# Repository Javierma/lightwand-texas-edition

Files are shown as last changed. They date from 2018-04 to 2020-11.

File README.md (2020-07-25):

# Lightwand Texas Edition v 2.0

Copyright (C) May 2018, Javier Martínez Arrieta

The LightWand Texas Edition controller is released under an Attributtion-ShareAlike 4.0 International (CC BY-SA 4.0). Therefore, anyone is free to:

-Share - copy and redistribute the material in any medium or format

-Adapt - remix, transform, and build upon the material for any purpose, even commercially.

This is the Lightwand Texas Edition project, a light painting project that makes use of a TM4C123 (TIVA) board as a controller in order to read the image information and transmit it to the LED strip according to the settings.

The following folders contain all the necessary things:
	
-CCS project: Contains the software code to be uploaded to the board

-Eagle project: Contains the hardware design

-FreeCAD design: Contains the 3D design of the box to cover the hardware

-Sketchup design: Contains the 3D design of the hardware

-Lightwand Texas Edition English Guide: The manual to be used to know about the different HW parts, soldering steps, creating PNM images and how to navigate through the different menus 

In order to know how to import the project in Code Composer Studio, configure the project settings and configure interrupts, go to the [wiki page](https://github.com/Javierma/lightwand-texas-edition/wiki)

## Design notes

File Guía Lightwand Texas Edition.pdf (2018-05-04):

# Lightwand Texas Edition

V 1.0

## Desarrollado por Javier Martínez Arrieta

## (martinezarrietajavier@gmail.com)

## Disponible en

## https://github.com/JavierMA/lightwand-

## texas-edition (https://github.com/JavierMA/lightwand-texas-edition)

### Índice

5.5. Suelde la tira de pines hembra (8 pines) para conectar el acelerómetro ADXL345
5.10. Desuelde los cables de la tira de LEDs, que podrá reutilizar para crear un cable más
5.11. Conecte el extremo libre del los cables con un conector molex hembra para conseguir
5.13. Finalmente, conecte el conector molex hembra con el macho ya soldado en la placa: 12
7.5. Paso 5: Rote la imagen 180º (únicamente si el movimiento del Lightwand lo hace de

### Tabla de figuras

### 1. Acerca del autor

Este Proyecto ha sido desarrollado por Javier Martínez Arrieta, ingeniero telemático (telecomunicaciones) aficionado a la electrónica. En caso de querer resolver una duda, saber más o incluso un posible curso puede escribir a martinezarrietajavier@gmail.com

Este y otros proyectos pueden encontrarse en https://www.github.com/JavierMA

### 2. Agradecimientos

Este proyecto está basado en el Proyecto Lightwand kosmonaut, desarrollado por Pablo de Miguel Morales (https://github.com/pablodmm), quien me ayudó en la realización de este Proyecto, por lo que me gustaría agradecerle a él y otras personas de AETEL que también me ayudaron. Adicionalmente, LightWand Kosmonaut se basa en el Proyecto de light painting desarrollado por Michael Ross. (http://mrossphoto.com/wordpress32/)

Por otra parte, algunas de las funciones que pueden verse en el software están basados o directamente recogidos de de ejemplos del curso de EdX ‘Embedded systems: shape the world’ o de Jonathan Valvano http://users.ece.utexas.edu/~valvano/arm/.

Para finalizar los agradecimientos y menciones, quisiera agradecer a Paul Stoffregen su tutorial (https://www.pjrc.com/tech/8051/ide/fat32.html) acerca de cómo entender el sistema de ficheros FAT 32 y su funcionamiento.

### 3. Licencia

El controlador LightWand Texas Edition se encuentra bajo la licencia Creative Commons, Attributtion-ShareAlike 4.0 International (CC BY-SA 4.0). Por ello, cualquiera es libre de:

- Compartir — Copiar y redistribuir el material en cualquier medio o formato
- Adaptar — Mezclar, transformar y crear a partir de este material, incluso con fines comerciales.

### 4. Imágenes compatibles

Las imágenes compatibles con el Lightwand Texas Edition son las imágenes de extensión PNM, que pueden crearse o convertirse mediante programas como GIMP, del cual dispone de un tutorial más adelante en esta guía.

### 5. Proceso de soldadura

Los siguientes pasos muestran el que se considera es el mejor procedimiento para la soldadura de todos los componentes en la placa. Como regla general, se recomienda soldar en primer lugar los componentes de menor altura (en este caso, los componentes SMD), y por último los de mayor altura, que en este caso son las tiras de pines macho que conectan la TIVA con la placa que contiene todos los componentes.

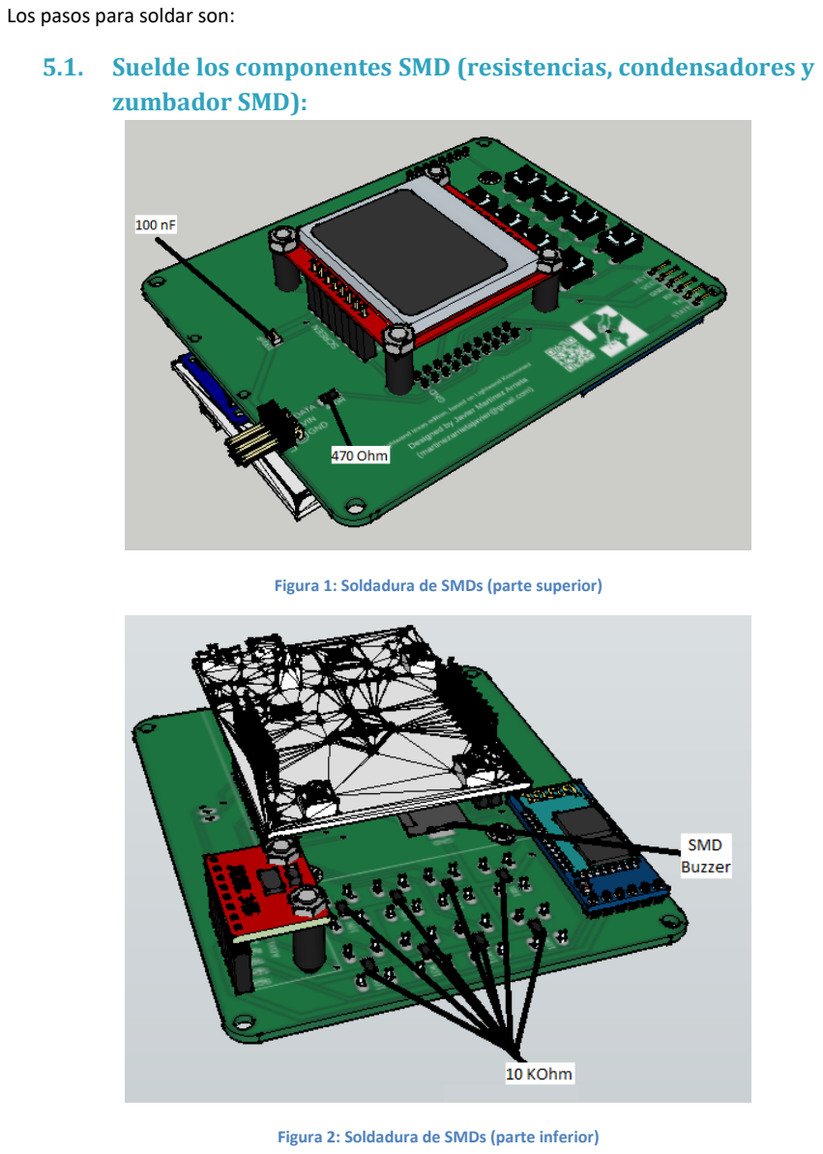
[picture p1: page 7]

Los pasos para soldar son:

### 5.1. Suelde los componentes SMD (resistencias, condensadores y zumbador SMD):

Figura 1: Soldadura de SMDs (parte superior)

Figura 2: Soldadura de SMDs (parte inferior)

### 5.2. Suelde los pulsadores:

Figura 3: Soldadura de pulsadores

### 5.3. Suelde el conector a la tira de LEDs:

Figura 4: Conector de la tira LED

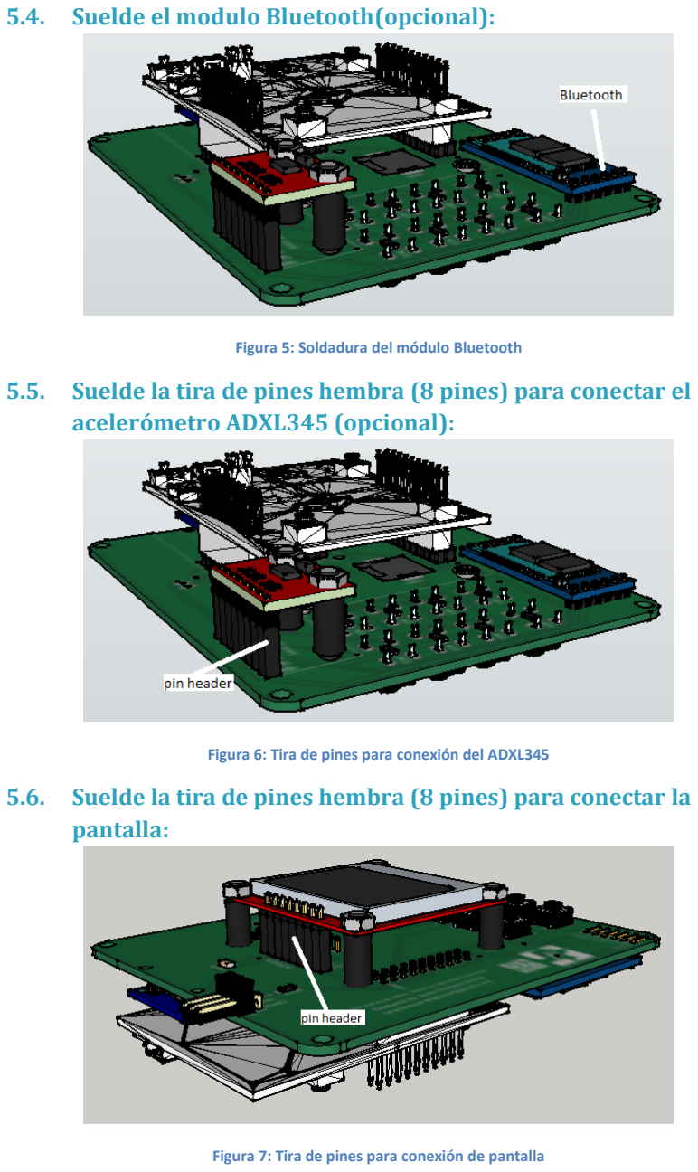
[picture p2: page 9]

### 5.4. Suelde el modulo Bluetooth(opcional):

Figura 5: Soldadura del módulo Bluetooth

### 5.5. Suelde la tira de pines hembra (8 pines) para conectar el acelerómetro ADXL345 (opcional):

Figura 6: Tira de pines para conexión del ADXL345

### 5.6. Suelde la tira de pines hembra (8 pines) para conectar la pantalla:

Figura 7: Tira de pines para conexión de pantalla

### 5.7. Suelde el adaptador de tarjetas microSD:

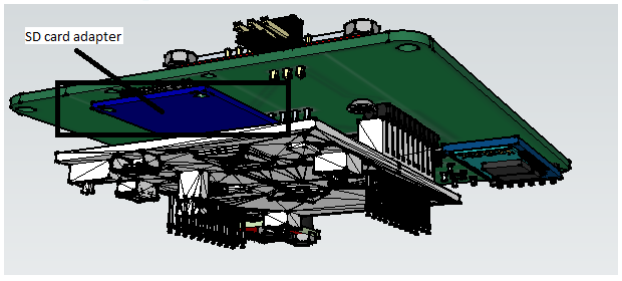
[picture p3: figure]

Figura 8: Soldadura del adaptador de microSD

### 5.8. A continuación, suelde las tiras de pines macho (2x10):

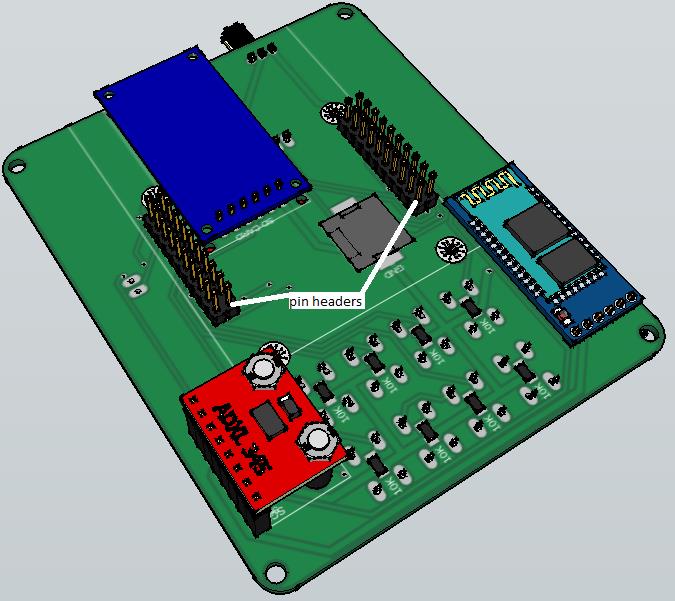
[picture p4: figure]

Figura 9: Soldadura de las tiras de pines macho

### 5.10. Desuelde los cables de la tira de LEDs, que podrá reutilizar para crear un cable más largo que unirá la tira con la placa:

Figura 10: Retirada de cable del final de la tira de LEDs

### 5.11. Conecte el extremo libre de los cables con un conector molex hembra para conseguir un resultado como el siguiente:

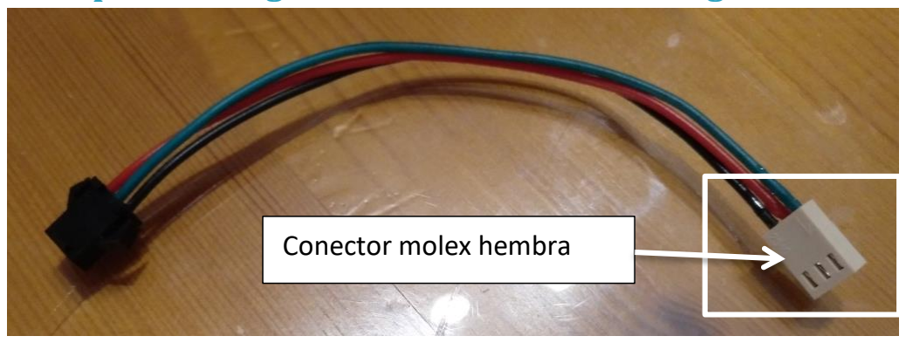
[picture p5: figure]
Conector molex hembra

Figura 11: Soldadura con el conector molex hembra

### 5.12. Conecte el conector negro del cable con el del cable unido a la tira de LEDs:

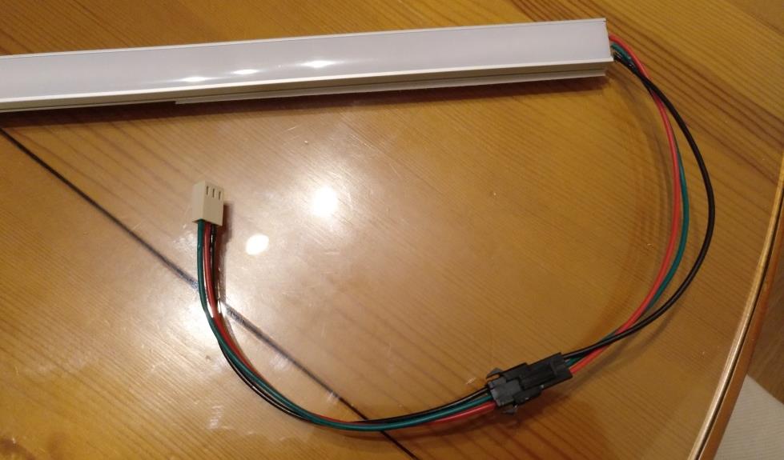
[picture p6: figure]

Figura 12: Conexión entre conectores negros

### 5.13. Finalmente, conecte el conector molex hembra con el macho ya soldado en la placa:

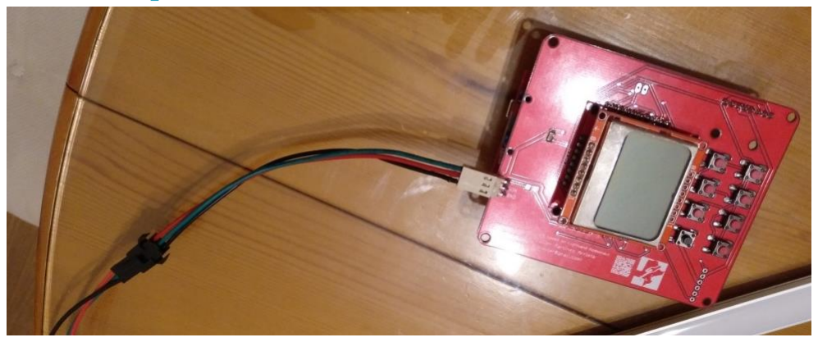
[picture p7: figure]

Figura 13: Conexión entre la tira de LEDs y la placa

### 6. Menús

Una vez que la placa recibe alimentación, en primer lugar se verificará que la tarjeta microSD conectada está formateada como FAT32.

Figura 14: Verificación del Sistema de ficheros

Tras la verificación, comienza la inicialización y se mostrará el menú principal:

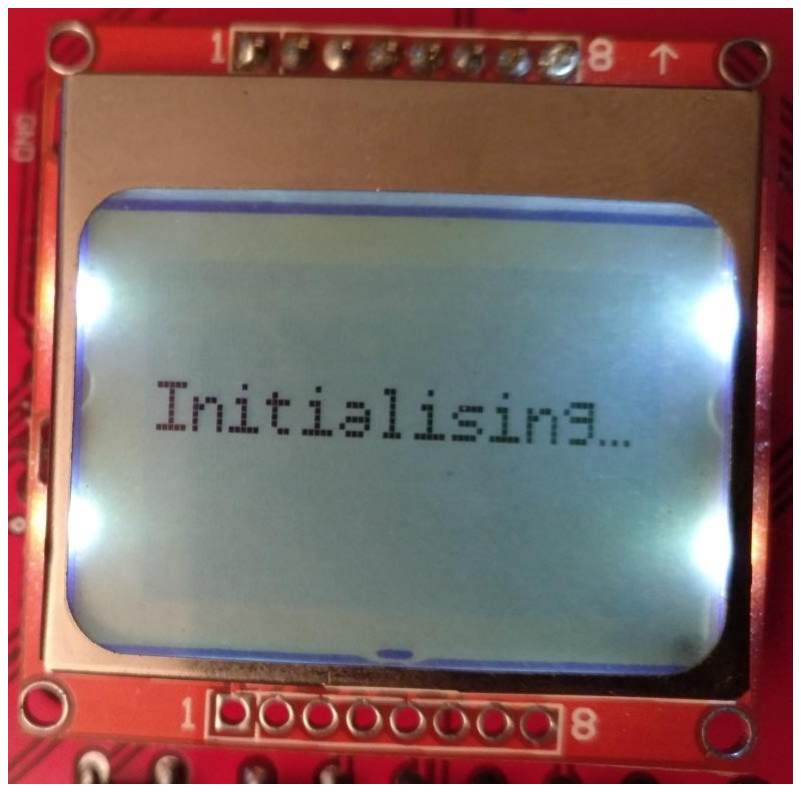
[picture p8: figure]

Figura 15: Inicialización

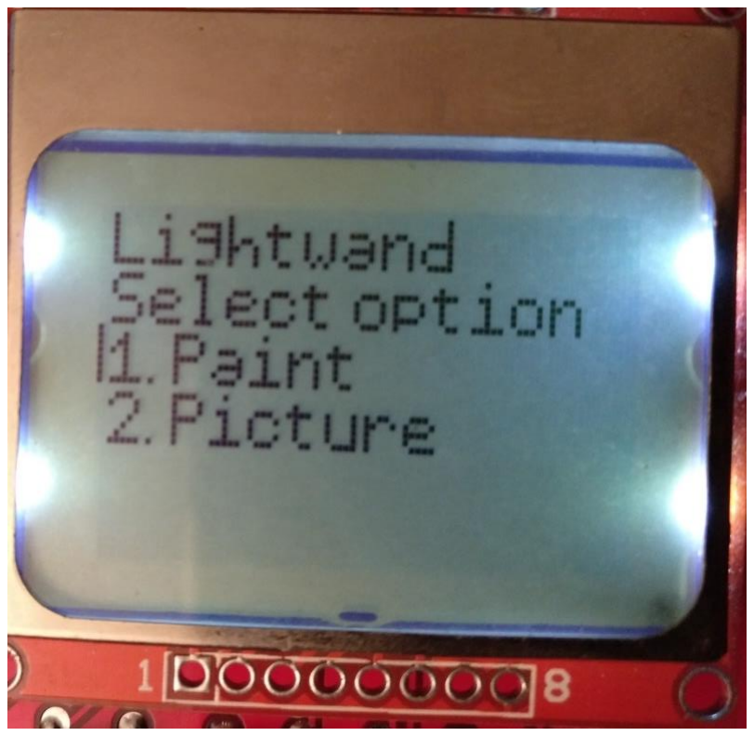
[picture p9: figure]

Figura 16: Menú principal

Encontrará dos opciones en el menú:

-Paint: Esta opción le permitirá elegir qué LED(s) iluminar y en qué color, de forma que pueda ‘escribir’ en el aire tal como muestra la siguiente imagen de ejemplo:

Figura 17: Ejemplo de escritura con el Lightwand

-Picture: Esta opción le permitirá seleccionar una imagen así como otras opciones (brillo, retardo y si reproducir un sonido para indicar el comienzo. La imagen que se muestra a continuación es un ejemplo:

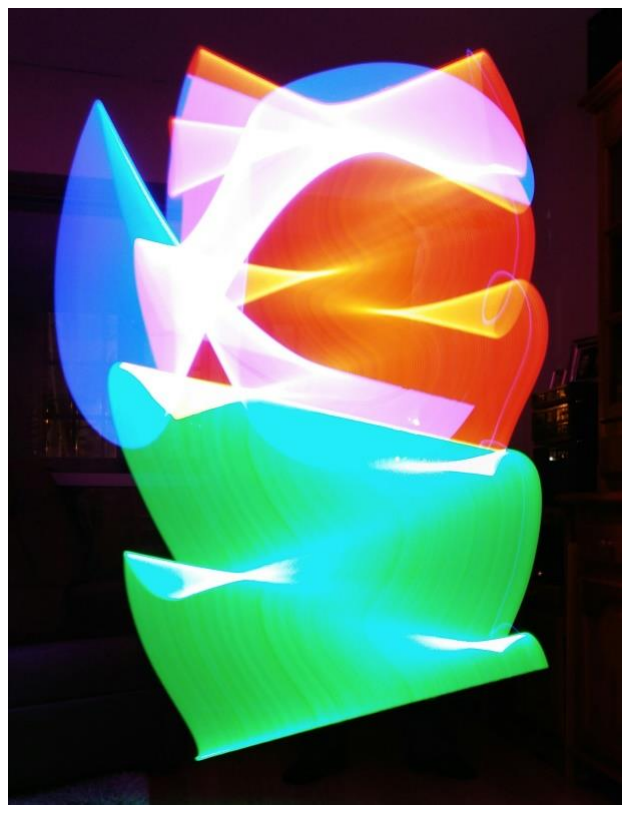
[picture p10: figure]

Figura 18: Ejemplo de imagen mediante el uso del Lightwand

Controles de menú:
Antes de mostrar la configuración por defecto, tenga en cuenta que aunque pueda modificarse la configuración de los botones mediante software, ésto no resulta posible para el botón de reset. Por defecto, la configuración es la siguiente:

Figura 19: Options buttons

-Reset (1): Configurado para el reinicio de la placa.

-Seleccionar(2): Configurado para seleccionar. La opción que se seleccionará muestra una barra vertical a su izquierda.

-Subir (3): Configurado para desplazarse a la línea superior.

-Backlight (4): Configurado para encender o apagar la luz de fondo.

-Incrementar (5): Incrementa el valor de configuración, por ejemplo, del brillo

-Bajar (6): Configurado para desplazarse a la línea inferior.

-Decrementar/volver al menú anterior (7): Decrementa el valor de una configuración como el retardo o vuelve al menú anterior

-Comenzar (8): En el caso del menú de imagen (picture), comienza la lectura de la imagen y la muestra fila a fila en la tira de LEDS. En el caso del pintado (paint menú) enciende o apaga los LEDs que se hayan configurado.

Menú paint:
El primer menú le permitirá seleccionar entre lo siguiente:

-Colores básicos: Uso del rojo, verde o azul en el LED o LEDs que se seleccionarán más Adelante.

-Random (aleatorio): Selecciona aleatoriamente los colores de cada LED, que se mostrarán una pez que se pulse el botón de comenzar.

-Monochrome (monocromo): Ilumina los LEDs en blanco y negro consecutivamente.

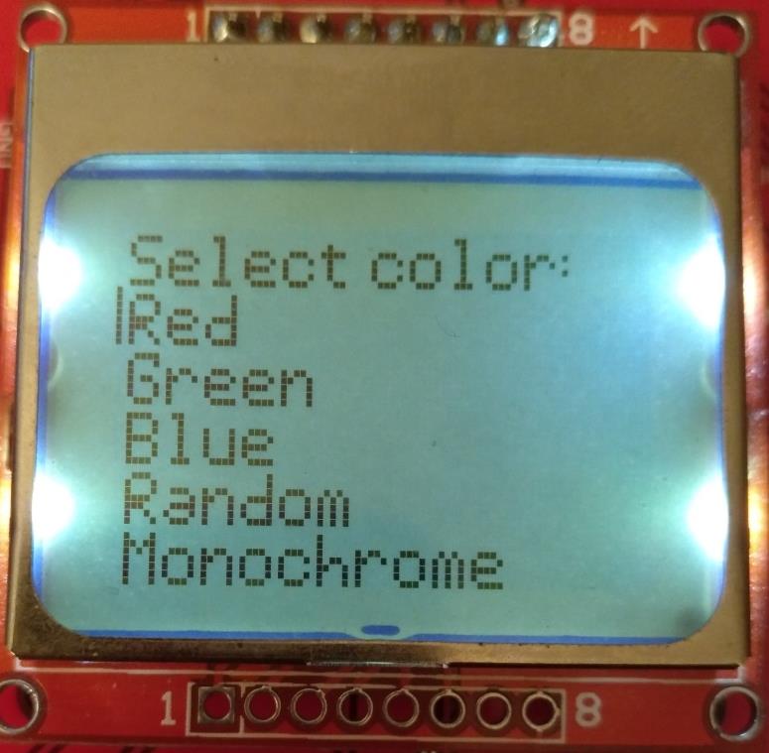
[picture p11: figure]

Figura 20: Menú de selección de color

Si la opción elegida es uno de los colores básicos, el siguiente menú le permitirá seleccionar el LED o LEDs que se iluminarán con dicho color. Existe la posibilidad de volver al menú anterior y elegir otro de los colores básicos y utilizarlos en otros LEDs. Cada vez que quiera que se ilumine un LED con el color elegido, deberá pulsar el botón de seleccionar. Una vez que esté listo para comenzar, presione el botón de comenzar para encender o apagar los LEDs.

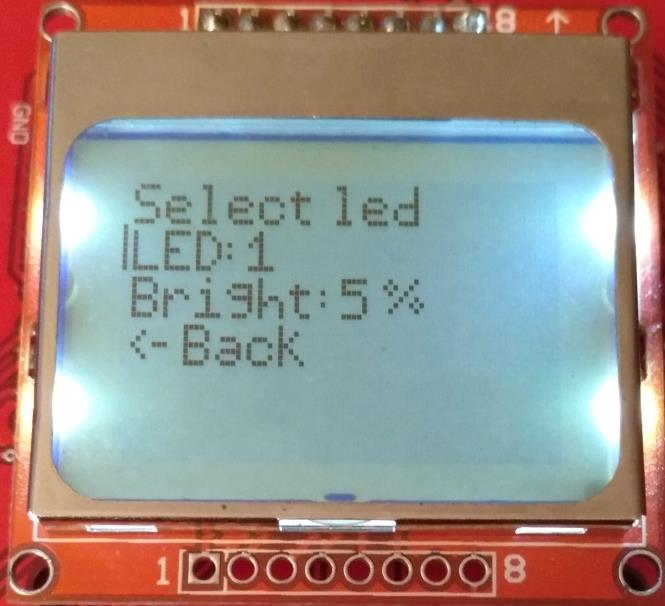
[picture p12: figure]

Figura 21: Menú paint, selección de LED y brillo

Menú imagen (picture):
Este menú le permitirá seleccionar la imagen, si reproducir un sonido al comenzar a mostrar la imagen, el nivel de brillo de color y el retardo entre las filas que se irán mostrando. Una configuración recomendada es de un 5% para el brillo y de 25-30 milisegundos de retardo.

Para seleccionar la imagen, desplácese hasta la línea inferior a ‘Current file’ y pulse el botón de selección, que mostrará un listado de las imágenes encontradas. Tenga en cuenta que en esta versión el máximo número de ficheros que se pueden mostrar es de 12. Además, las imágenes pueden estar hasta 2 subdirectorios por debajo del directorio raíz, aunque las pruebas demostraron que si todas las imágenes se encuentran en el directorio raíz éstas se encuentra más rápidamente.

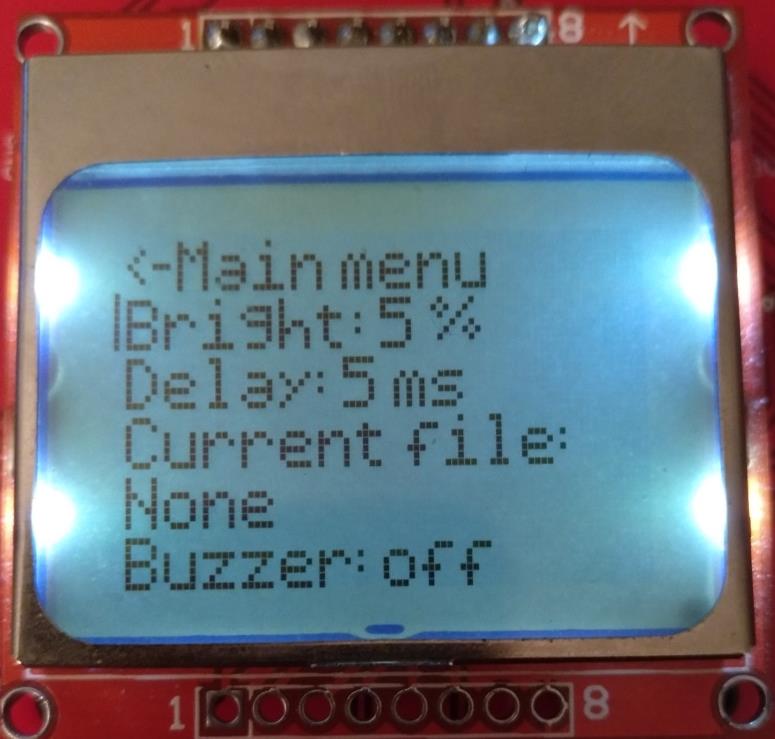
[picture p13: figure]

Figura 22: Picture menú

### 7. Formateo de imágenes con GIMP

Nota: Esta sección se escribió en su práctica totalidad por Pablo de Miguel Morales. Únicamente unas pocas líneas o modificaciones fueron escritas por el autor de esta guía.

Los siguientes pasos cubren la conversión de una imagen a un fichero PNM compatible mediante el uso de GIMP.

### 7.1. Paso 1: Seleccione una imagen

El primer paso consiste en encontrar una imagen a mostrar con el Lightwand. En general, existen dos aspectos a considerar:

- Una relación de aspecto no superior a 1x2 en imágenes verticales. La razón se debe a que una mayor relación de aspecto supondría imágenes de 2 o más metros de altura, lo que puede dificultar la toma de la imagen.
- Una imagen no excesivamente detallada. Incluso aunque 144 píxeles se puede considerarse una buena resolución, no debe esperarse que el Lightwand muestre imágenes con alta precisión.

Para esta guía, la imagen elegida fue “El beso” de Gustav Klimt¹
:

1
The Kiss(Gustav Klimt)(1909), Wikipedia, http://en.wikipedia.org/wiki/The_Kiss_%28Klimt%29

Figura 23: Gustav Klimt Raw Image

La resolución elegida para esta imagen fue de 3768x5051. Cuanto mayor sea la resolución mejor será la imagen, ya que cualquier cambio que se produzca en imágenes de menor calidad serán más notables en el resultado final.

Una vez seleccionada la imagen, vaya al siguiente paso.

### 7.2. Paso 2: Abra la imagen con GIMP

El Segundo paso consiste en abrir la imagen con GIMP a través de File -> Open.

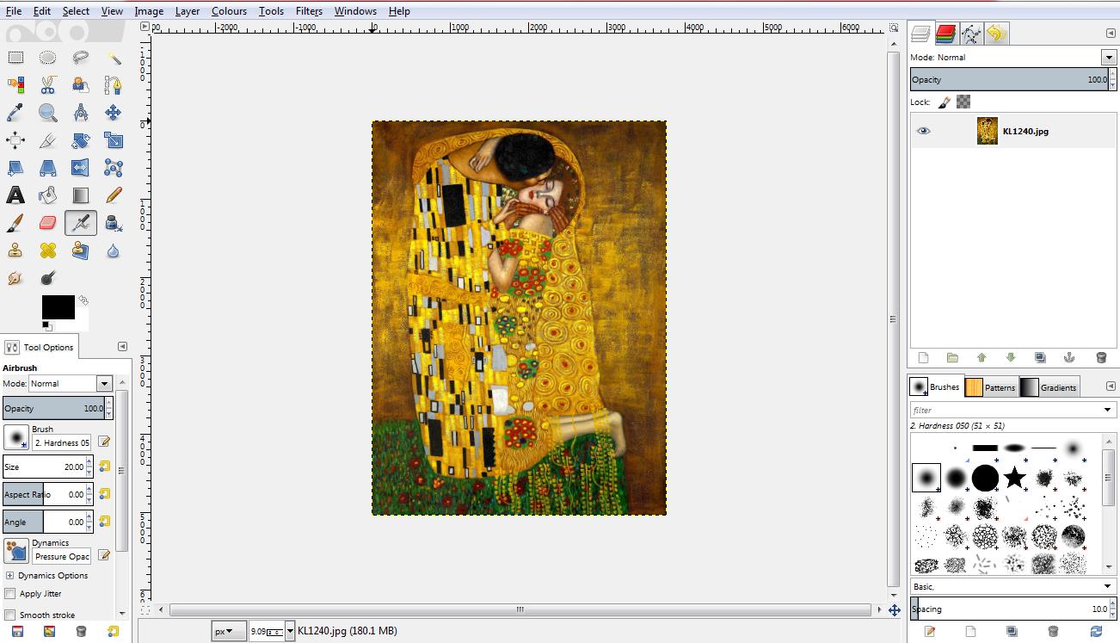
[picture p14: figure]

Figura 24: GIMP File Open

Una vez abierto el fichero, proceda al siguiente paso.

### 7.3. Paso 3: Corte la parte deseada de la imagen

Este paso consiste en cortar la imagen que será mostrada con el lightwand. Este paso normalmente consiste en separar la parte principal del resto de la imagen. A través de este proceso, se elimina el canvas (lienzo), mejorando notablemente la imagen final. Sin estas líneas rectas, cualquier error en el proceso fotográfico será mucho menos notable.

Para recortar la imagen deseada, duplique en primer lugar la capa original hacienda clic con el botón derecho del ratón en la ventana de capas (layers) y seleccionando ‘duplicar capa’ (duplicate layer).

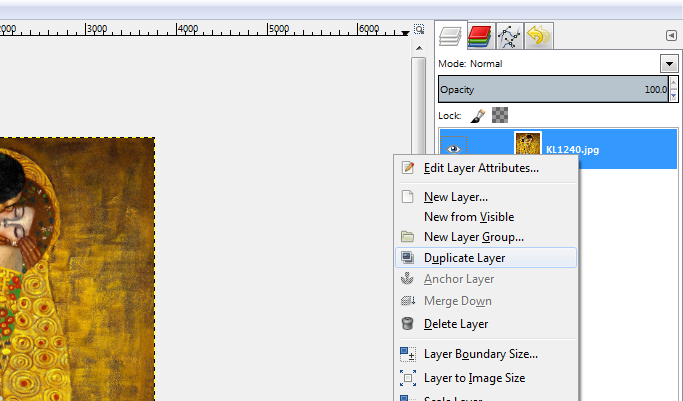
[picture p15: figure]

Figura 25: GIMP Duplicate Layer

Una vez duplicada la capa, recorte la figura principal con la herramienta de selección libre (Free-selection tool o atajo I), lo cual puede resultar un poco tedioso. Tras aplicar el recorte, transfiéralo a una nueva capa mediante la opción ‘To new layer’ (atajo Ctrl+Mayús+N).

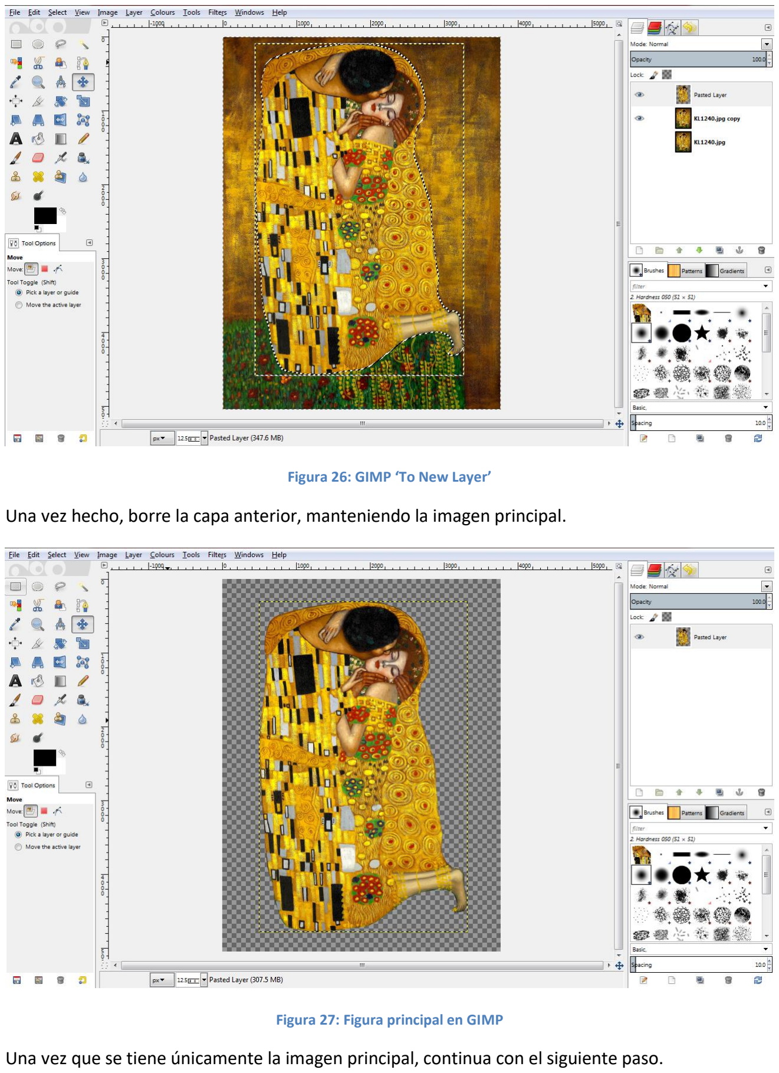
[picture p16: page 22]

Figura 26: GIMP ‘To New Layer’

Una vez hecho, borre la capa anterior, manteniendo la imagen principal.

Figura 27: Figura principal en GIMP

Una vez que se tiene únicamente la imagen principal, continua con el siguiente paso.

### 7.4. Paso 4: Redimensione la imagen

El cuarto paso consiste en redimensionar la imagen para su adaptación a la tira de 144 LEDs, lo que significa un ancho de 144 píxeles. Para ello, utilice la herramienta de escalado (scale), accesible con el atajo Mayúscula + T.

Con la herramienta abierta, en primer lugar seleccione la opción de escalado proporcional y, posteriormente, establezca un ancho (width) de 144 píxeles. Para finalizar este paso, pulse el botón ‘Scale’

Figura 28: Escalado proporcional en GIMP | Figura 29: Parámetros de escalado en GIMP

Una vez escalada la imagen, cambie el tamaño del lienzo a través de Image -> Fit Canvas to Layers. El nuevo lienzo tendrá un ancho de 144 píxeles.

Figura 30: Imagen redimensionada en GIMP

Con la imagen ya redimensionada, proceda al siguiente paso

### 7.5. Paso 5: Rote la imagen 180º (únicamente si el movimiento del Lightwand lo hace de

abajo a arriba)
El quinto paso consiste en rotar la imagen 180º para realizar el movimiento del lightwand de abajo a arriba. Este paso únicamente es importante si la imagen estará en contacto con el suelo. Si no es el caso, puede continuar con el siguiente paso. Para rotar la imagen, utilice la herramienta Rotate (atajo Mayúscula + R) y seleccione ‘rotar 180º’.

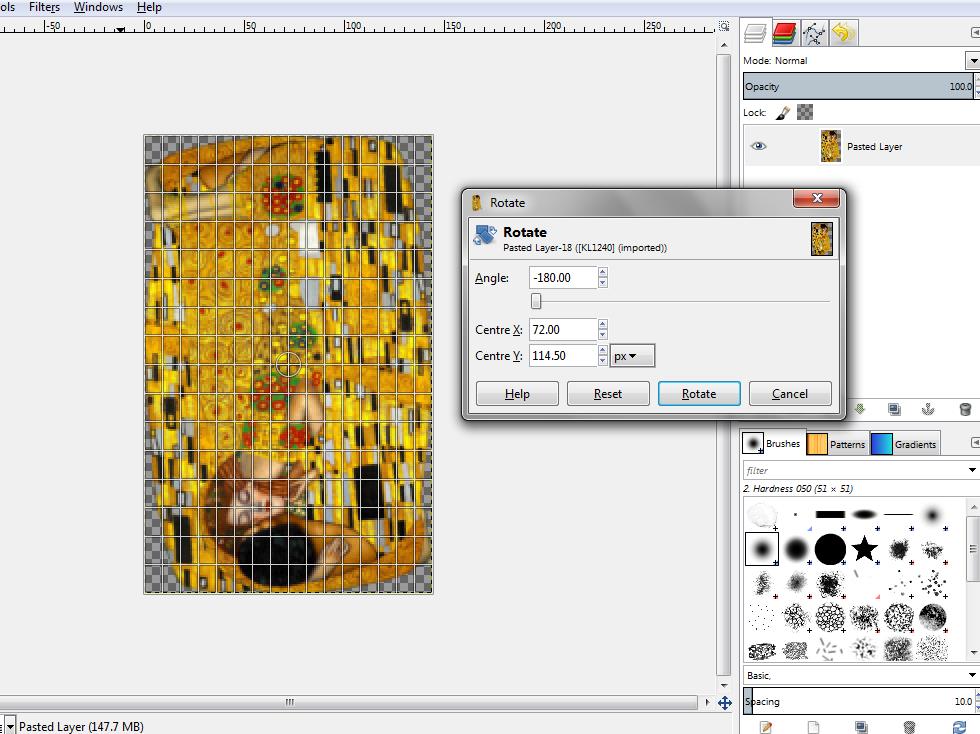
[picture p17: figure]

Figura 31: Rotación de imagen con GIMP

El LightWand lee la imagen comenzando por la fila superior, que será la primera en mostrarse.

### 7.6. Paso 6: Añada un fondo negro

El sexton paso consiste en añadir un fondo negro a la imagen para que no se muestren en el LightWand. Esto puede realizarse en la ventana ‘Layer’ y haciendo click en New Layer -> Foreground Color.

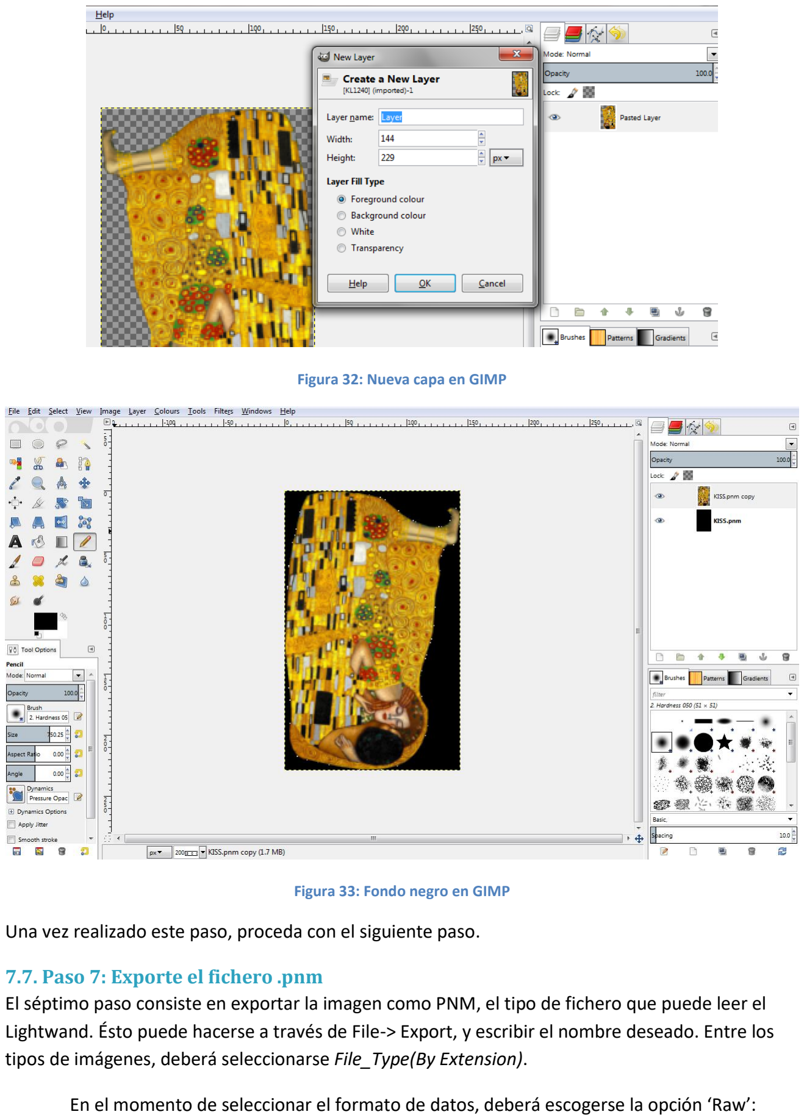
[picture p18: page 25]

Figura 32: Nueva capa en GIMP

Figura 33: Fondo negro en GIMP

Una vez realizado este paso, proceda con el siguiente paso.

### 7.7. Paso 7: Exporte el fichero .pnm

El séptimo paso consiste en exportar la imagen como PNM, el tipo de fichero que puede leer el Lightwand. Ésto puede hacerse a través de File-> Export, y escribir el nombre deseado. Entre los tipos de imágenes, deberá seleccionarse File_Type(By Extension).

En el momento de seleccionar el formato de datos, deberá escogerse la opción ‘Raw’:

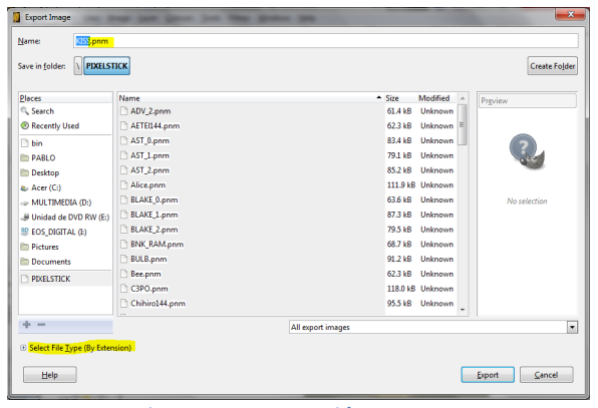
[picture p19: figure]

Figura 34: Exportación en GIMP

Figura 35: Formato de datos raw en GIMP

Finalizado este paso, el proceso con GIMP habrá finalizado y podrá almacenar la imagen en la tarjeta microSD.

### 8. Configuración de la cámara del móvil

Para poder realizar fotografías con una cámara de móvil, deberá seleccionarse, si se encuentra disponible, el modo light painting. Si no es el caso, deberá configurar el modo manual. Aunque es posible que la cámara del móvil no disponga de este modo o no sea compatible, un gran número de modelos actuales permiten realizar este tipo de fotografías. Adicionalmente, aplicaciones como Camera FV-5 pueden ser útiles para este tipo de fotografía.

El siguiente ejemplo muestra cómo configurar el modo manual con la cámara del bq Aquaris X5, que probablemente será muy parecido al de otros dispositivos:

- Con la aplicación de la cámara abierta, pulse el círculo con la A en su interior para que se muestre, entre otros, el modo manual (aquel con una M en el interior del círculo):

Figura 36: Modo automático de la cámara

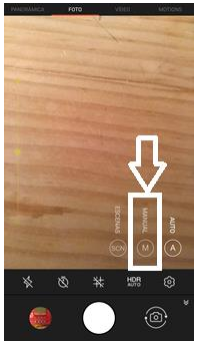
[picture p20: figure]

Figura 37: Presione el modo manual

- En primer lugar, seleccione el enfoque automático o AF:

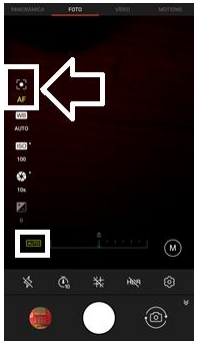
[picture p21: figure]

Figura 38: Selección de autoenfoque

- En segundo lugar, seleccione un balance de blancos automático, de forma que la aplicación se encargará de forma automática.

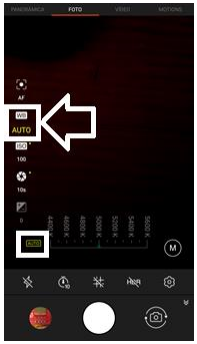
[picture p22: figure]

Figura 39: Selección automática de balance de blancos

- En tercer lugar, seleccione la ISO más baja posible. De esta manera, la imagen tendrá un ruido menor para este tipo de fotografías.

Figura 40: Selección de ISO

- -En siguiente lugar, seleccione el tiempo de disparo, que dependerá de la imagen a fotografiar. El tiempo máximo para esta cámara es de 10 segundos, que será es que establezcamos.

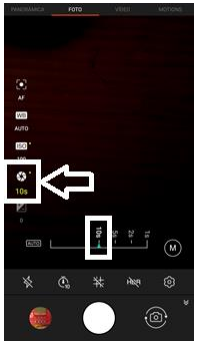
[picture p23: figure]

Figura 41: Tiempo de disparo

- Finalmente, seleccione el tiempo de espera antes de comenzar a realizar la fotografía, de manera que tenga tiempo de prepararse antes de que empiece a hacerse la foto.

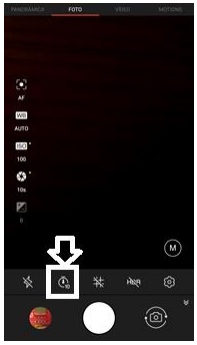
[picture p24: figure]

Figura 42: Selección de tiempo de espera

### 9. Recomendaciones de alimentación

Para conseguir que las imágenes que se muestren tengan Buena calidad, se recomienda el uso de una Power Bank de 5V a la salida y corriente de al menos 2000mAh. Según la documentación de la tira de LEDs, cada uno tiene un consume de alrededor de 60mA con el brillo máximo establecido, lo que supone un consumo de 8,64A con todos los LEDs brillando al máximo, por lo que quizás desee que el alimentador ofrezca una mayor corriente a la salida.

### 10. Trabajo futuro

Con motivo de añadir opciones adicionales que a su vez permitan un uso más fácil, el diseño hardware permite la adición de un módulo bluetooth y un acelerómetro ADXL345, aunque el código que permita su uso está por implementar.

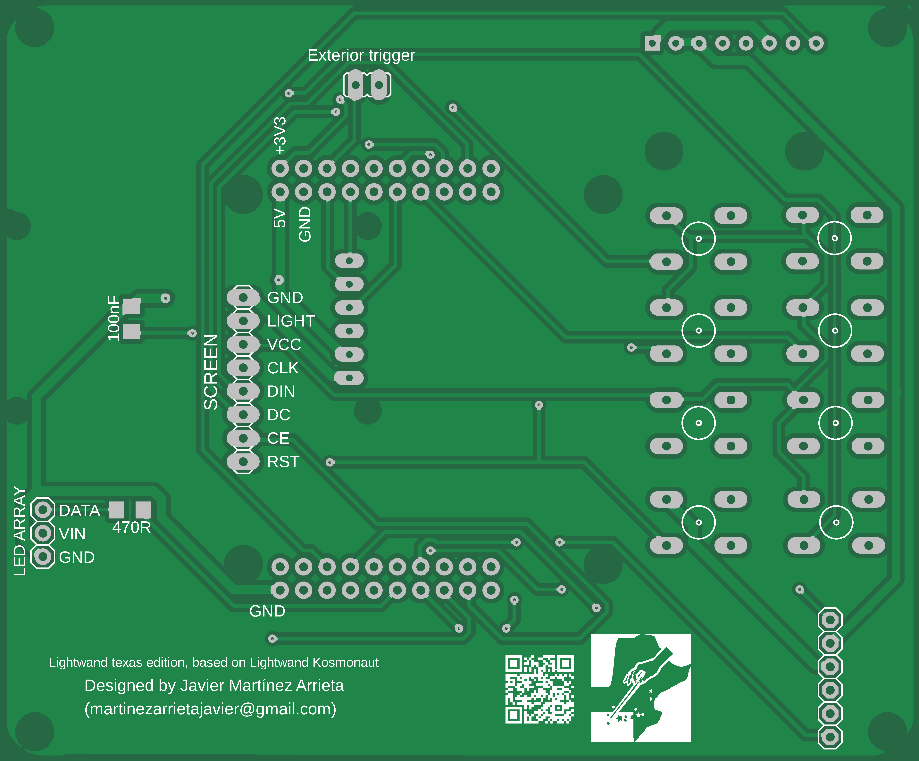
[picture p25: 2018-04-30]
eagle project/Lightwand_USB_power/eagleUp/eagleUp_LightWand_USB_power_board_top.png

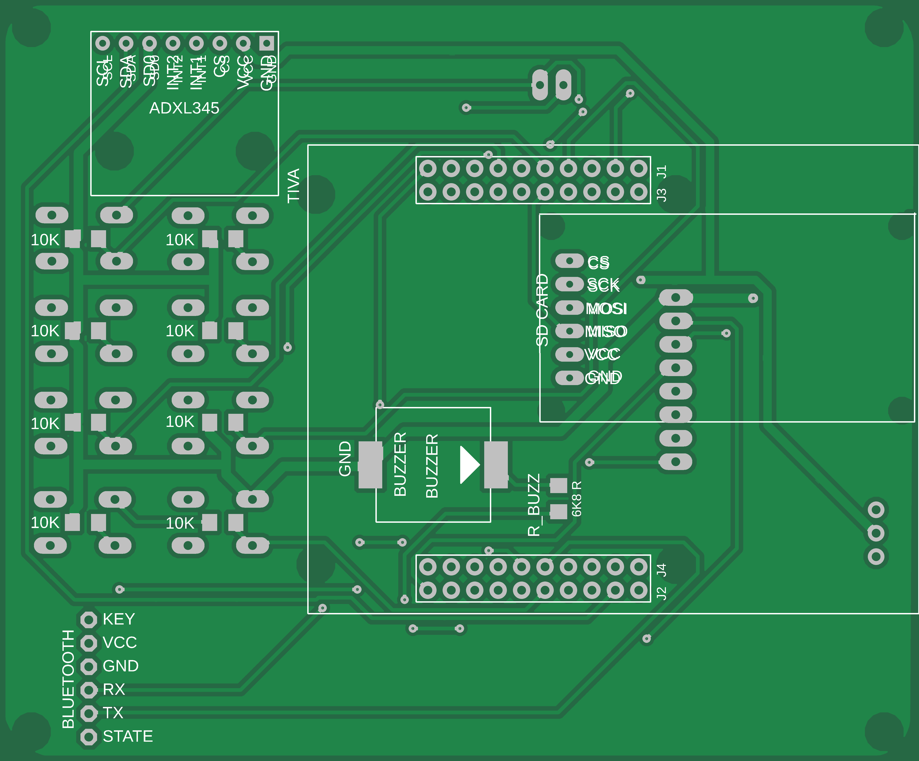
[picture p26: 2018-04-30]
eagle project/Lightwand_USB_power/eagleUp/eagleUp_LightWand_USB_power_board_bottom.png

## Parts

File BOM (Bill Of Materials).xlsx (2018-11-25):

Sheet: BOM ES
Componente | Cantidad
Tira led WS2812 (1m, 144 leds en total) | 1
Resistencia 470 Ohm SMD 1206 | 1
Resistencia 10 kOhm SMD 1206 | 9
Tira pines macho 2x10 | 2
Condensador 100 nF SMD 1206 | 1
Tira pines hembra 1x40 | 1
Lector MicroSD Catalex | 1
Perfil aluminio 1m | 1
Pantalla LCD PCD8544 | 1
Conector Molex acodado 3 pines macho | 1
Conector Molex hembra 3 pines | 1
Pulsador | 8
Zumbador Murata PKLCS12 | 1
Separador plástico 3x8 mm | 6, 8 en caso de usar el ADXL345
Módulo Bluetooth HC-05 o HC-06 (opcional) | 1
Acelerómetro ADXL345 (opcional) | 1

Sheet: BOM EN
Component | Quantity
WS2812 LED strip (1m, 144 LEDs in total) | 1
470 Ohm SMD 1206 Resistor | 1
10 kOhm SMD 1206 Resistor | 9
2x10 male pin header | 2
100 nF SMD 1206 Capacitor | 1
1x40 female pin header | 1
MicroSD Catalex adapter | 1
1m aluminium profile | 1
PCD8544 LCD screen | 1
3 pins male Molex angled connector | 1
Conector Molex hembra 3 pines | 1
Button | 8
Murata PKLCS12 buzzer | 1
3x8 mm plastic separator | 6, 8 if using the ADXL345 accelerometer
HC-05 o HC-06 Bluetooth module (optional) | 1
ADXL345 Accelerometer (optional) | 1

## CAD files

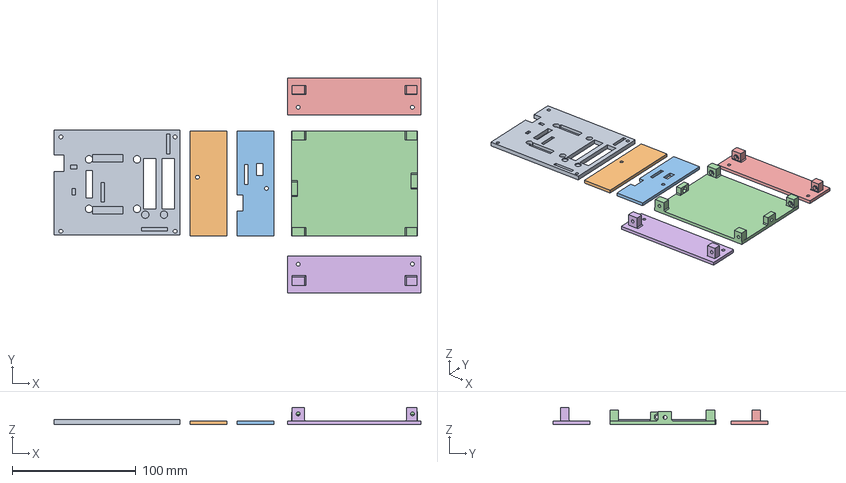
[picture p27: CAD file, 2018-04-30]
eagle project/Lightwand_USB_power/eagleUp/lightwand_box_for_printing.FCStd
297.0 x 174.0 x 14.0 mm
final top
final back
final front
bottom
left side001

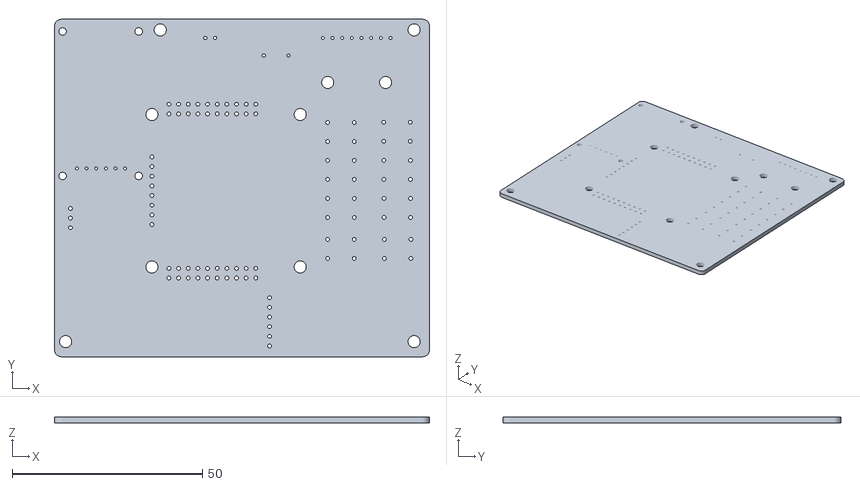
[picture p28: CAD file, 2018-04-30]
eagle project/Lightwand_USB_power/lightwand_board.stl
98.7 x 88.8 x 1.60

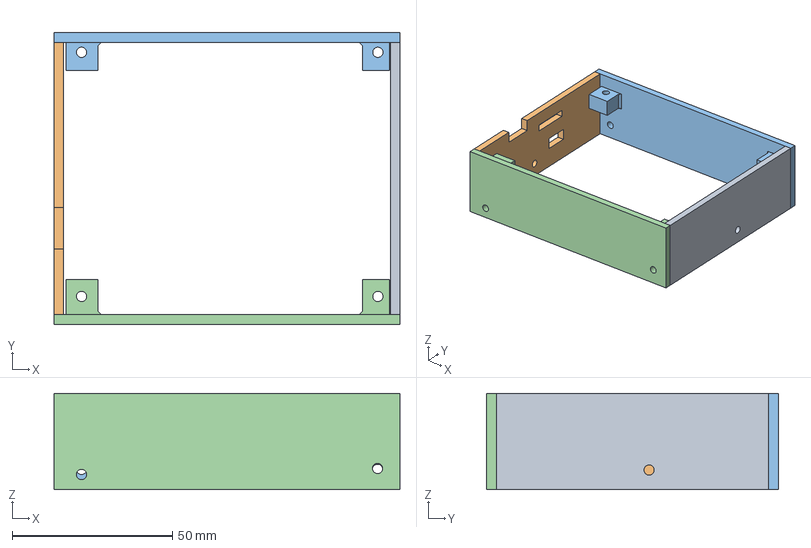
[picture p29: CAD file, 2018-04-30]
FreeCAD design/lightwand_box.FCStd
108.0 x 91.0 x 30.0 mm
final back
final front
left side final001
right side final

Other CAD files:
CCS project/lightwand_texas_edition/Debug/optimizerAssistant/opt_for_speed__0/main.obj
CCS project/lightwand_texas_edition/Debug/optimizerAssistant/opt_for_speed__3/main.obj
CCS project/lightwand_texas_edition/Debug/optimizerAssistant/opt_for_speed__2/main.obj
CCS project/lightwand_texas_edition/Debug/optimizerAssistant/opt_for_speed__1/main.obj
CCS project/lightwand_texas_edition/Debug/optimizerAssistant/opt_for_speed__4/main.obj
CCS project/lightwand_texas_edition/Debug/optimizerAssistant/opt_for_speed__5/main.obj
CCS project/lightwand_texas_edition/Debug/optimizerAssistant/opt_for_speed__0/uart.obj
CCS project/lightwand_texas_edition/Debug/optimizerAssistant/opt_for_speed__1/tm4c123gh6pm_startup_ccs.obj
CCS project/lightwand_texas_edition/Debug/optimizerAssistant/opt_for_speed__2/uart.obj
CCS project/lightwand_texas_edition/Debug/optimizerAssistant/opt_for_speed__3/Nokia5110.obj
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

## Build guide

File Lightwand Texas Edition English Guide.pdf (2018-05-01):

# Lightwand Texas Edition

V 1.0

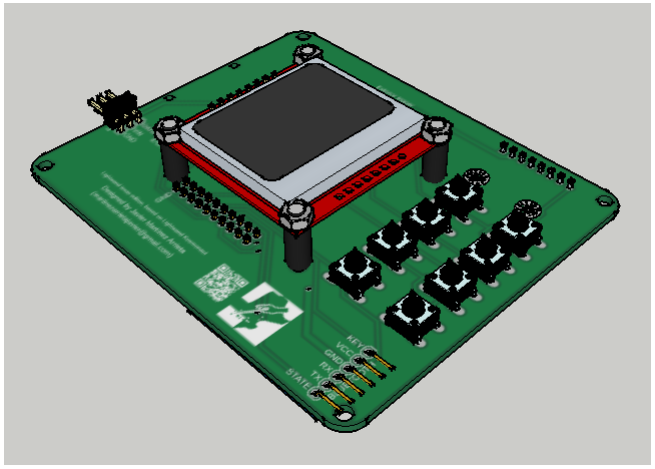
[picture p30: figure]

## Designed by Javier Martínez Arrieta

## (martinezarrietajavier@gmail.com)

## Available at

## https://github.com/JavierMA/lightwand-

## texas-edition (https://github.com/JavierMA/lightwand-texas-edition)

### Contents

5.5. Solder the female pin header (8 pins) to connect the ADXL345 accelerometer (optional): 9
5.10. De-solder the cables from the LED strip, which can be reused to create a longer cable
5.11. Connect the free extreme of the cable to a female molex connector to have a result
7.5. Step 5: Turn the Image 180º (only if moving the lightwand from the bottom to the top) 24

### Table of figures

### 1. About the author

This project has been developed by Javier Martínez Arrieta, a Telematics (Telecommunication) engineer who also likes electronics. In case of willing to solve a doubt, know more or consider a possible course you can write an e-mail to martinezarrietajavier@gmail.com

This and other projects are available at https://www.github.com/JavierMA

### 2. Acknowledgements

This project is based on Lightwand kosmonaut, developed by Pablo de Miguel Morales (https://github.com/pablodmm) who helped me in many parts of this project, so I would really like to thank him and some other people from AETEL for their help and support. Besides, Lightwand Kosmonaut is based on the light painting project that was developed by Michael Ross. (http://mrossphoto.com/wordpress32/)

On the other hand, some of the functions available in the software are based or used from the examples of the course ‘Embedded systems: shape the world’ available in EdX and Jonathan Valvano’s http://users.ece.utexas.edu/~valvano/arm/.

To finish acknowledgments, I would also like to thank Paul Stoffregen for his tutorial (https://www.pjrc.com/tech/8051/ide/fat32.html) about understanding the FAT32 file system that helped me a lot to know how it works.

### 3. License

The LightWand Texas Edition controller is released under an Attributtion-ShareAlike 4.0 International (CC BY-SA 4.0). Therefore, anyone is free to:

- Share — copy and redistribute the material in any medium or format
- Adapt — remix, transform, and build upon the material for any purpose, even commercially.

### 4. Compatible images

Compatible images for the Lightwand Texas Edition are PNM files, which can be created with programs like GIMP. A detailed tutorial can be found later in this document.

### 5. Soldering steps

The following steps will show what I think is the best way to solder all of the components into the board. As a general rule, the recommendation is to first solder the lowest components (the SMD ones in this case), and finish soldering the highest ones (the male pin headers that connect the TIVA to the board).

The steps to solder are the following:

### 5.1. Solder the SMD components (resistors, capacitors and the SMD buzzer):

Figure 1: SMD soldering (top)

Figure 2: SMD soldering (bottom)

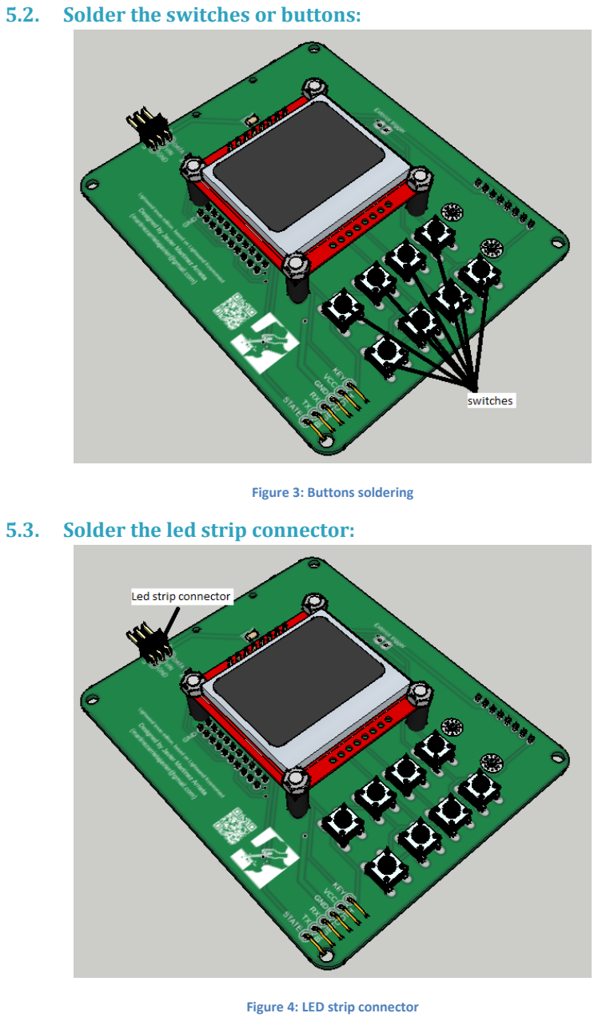
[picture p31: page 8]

### 5.2. Solder the switches or buttons:

Figure 3: Buttons soldering

### 5.3. Solder the led strip connector:

Figure 4: LED strip connector

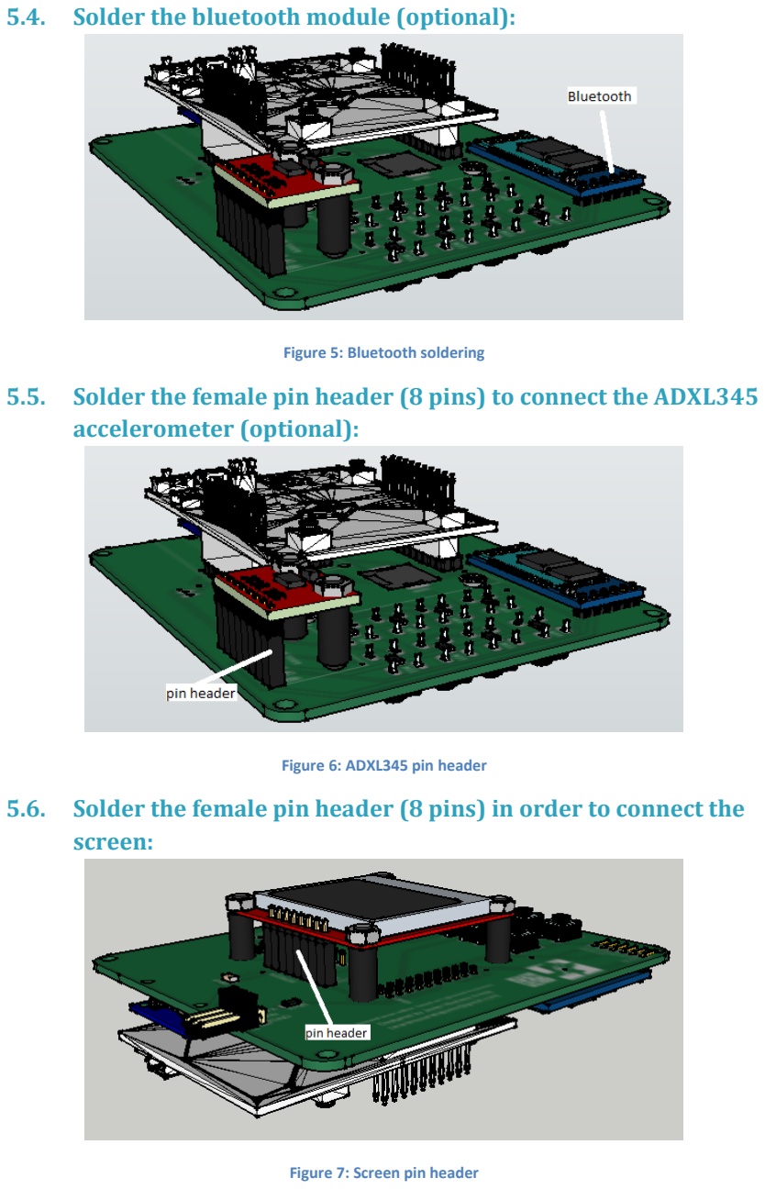
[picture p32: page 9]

### 5.4. Solder the bluetooth module (optional):

Figure 5: Bluetooth soldering

### 5.5. Solder the female pin header (8 pins) to connect the ADXL345 accelerometer (optional):

Figure 6: ADXL345 pin header

### 5.6. Solder the female pin header (8 pins) in order to connect the screen:

Figure 7: Screen pin header

### 5.7. Solder the SD card adapter:

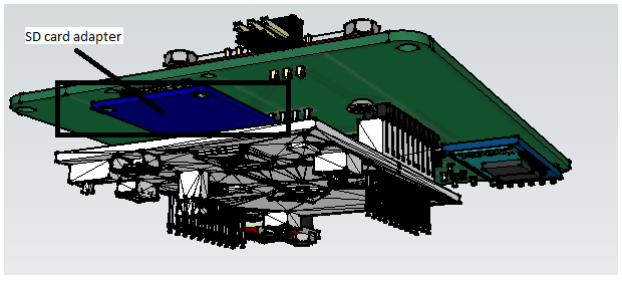
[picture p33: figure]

Figure 8: SD card adapter soldering

### 5.8. Next, solder the male pin headers (2x10):

Figure 9: TM4C pin headers connectors

### 5.10. De-solder the cables from the LED strip, which can be reused to create a longer cable that can be connected to the board:

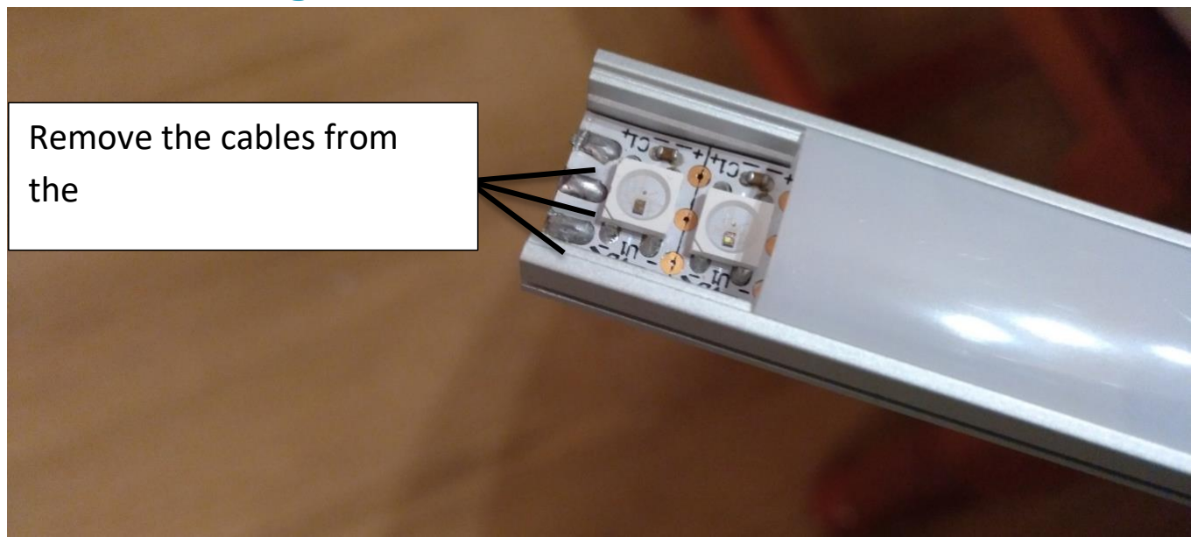
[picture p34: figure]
Remove the cables from the

Figure 10: LED strip cable removal

### 5.11. Connect the free extreme of the cable to a female molex connector to have a result like the following:

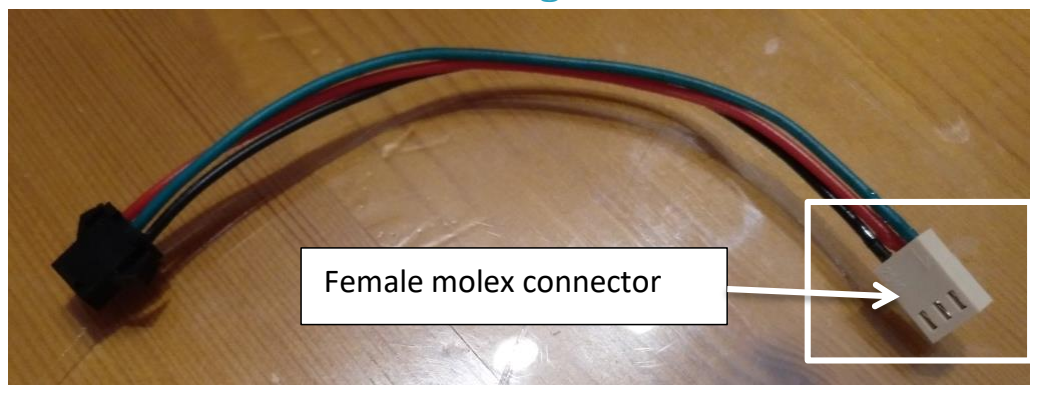
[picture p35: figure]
Female molex connector

Figure 11: Female molex connector soldering

### 5.12. Connect the black connector of the cable to the one attached to the led strip:


Figure 12: Extended cable connection

### 5.13. Finally, connect the female molex connector to the male one on the board:

Figure 13: Connection between the LED strip and the board

### 6. Menus

Once the board is powered, the first thing that will happen is a check to verify if a MicroSD card with FAT32 format is connected.

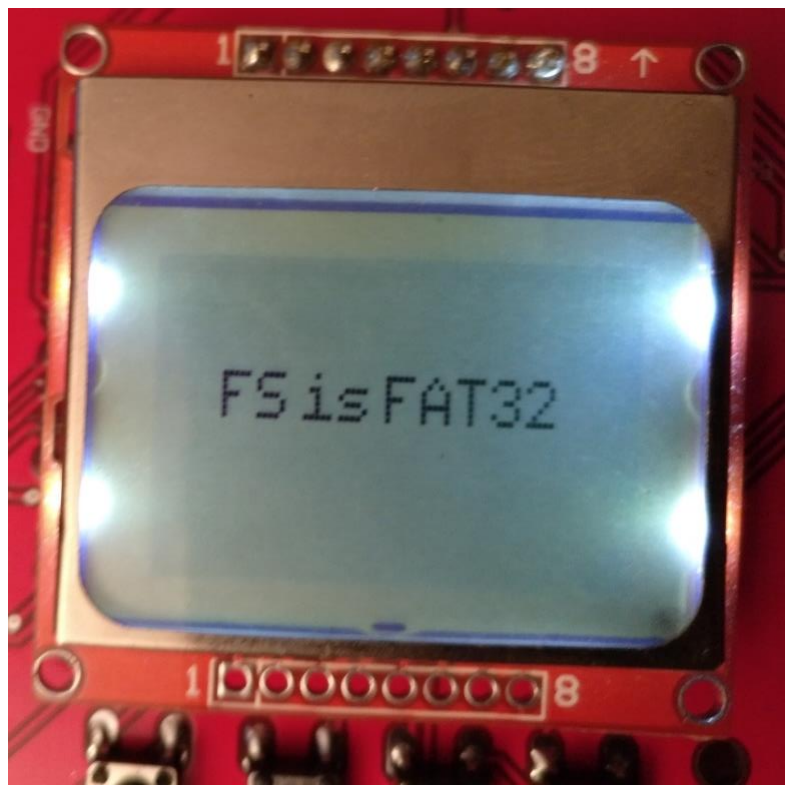
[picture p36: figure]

Figure 14: File system check

After the check, an initialization takes place and the main menu is shown:


Figure 15: Initialisation

Figure 16: Main menu

You will find two menu options:

-Paint: This option will let you choose which LED(s) to be light and in which colours, so you can ‘write’ in the air like in the following example:

Figure 17: Lightwand writing example

-Picture: This option will let you choose an image as well as select the different options (brightness, delay and whether to play a sound in order to indicate the start). The following image shows and example:


Figure 18: Lightwand picture example

Menu controls:
Before showing the default configuration, take into account that the reset button cannot be changed in software. By default, the configuration is as follows:

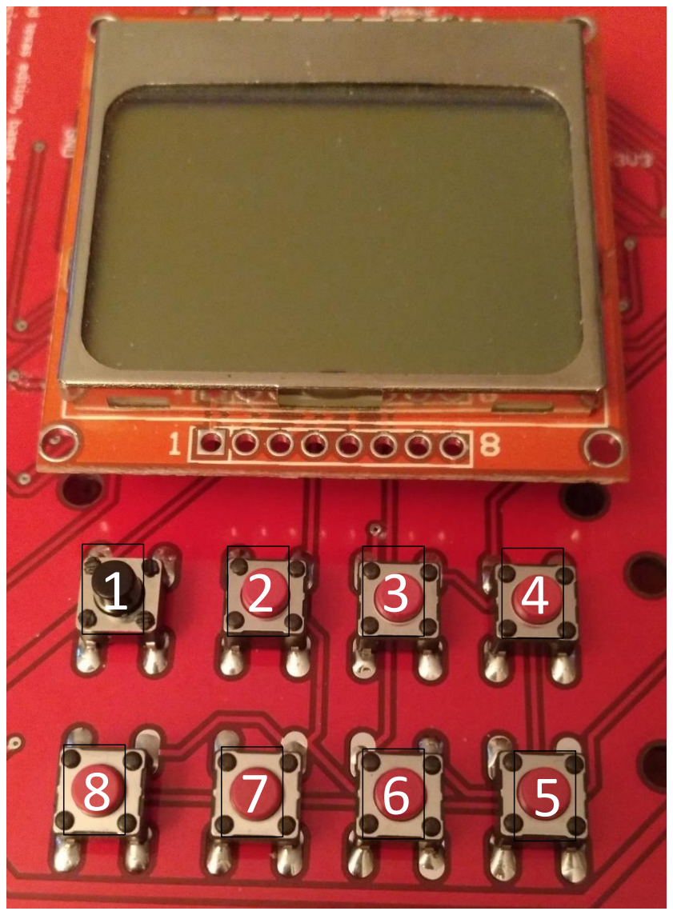
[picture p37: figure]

Figure 19: Options buttons

-Reset (1): This button is configured to reset the board in case it is necessary.

-Select (2): This button is configured to select the option. You can see a vertical bar on the left:

-Up (3): This button is configured to move up to the previous option in the shown menu.

-Backlight (4): Whether to set the backlight on or off.

-Increase (5): Increase the value of a setting like the brightness or the delay

-Down (6): This button is configured to move down to the next option in the shown menu.

-Decrease/go to the previous menu (7): Decreases the value of a setting like the brightness or go to the previous menu

-Start (8): In the case of the picture menu, starts reading the image and showing it by rows in the LED strip. In the case of the paint menu, lights the configured LEDs on or off.

Paint menu:
The first menu will let select the following:

-Basic colours: Whether to use the red, green or blue colour in the LED that will be selected later.

-Random: Randomly selects the colour of each LED, which will be shown once the start button is pressed.

-Monochrome: Consecutively lights the LEDs in white or black.


Figure 20: Paint colour menu

If the option selected is one of the basic colours, the next menu will let you choose to which LED or LEDS will be applied. It is possible to go to the previous menu and select another colour to apply it to other LEDS. Once the setting is done, press the select button to confirm the setting. Finally, press the start button to light on or light off the LEDs.

Figure 21: Paint menu, LED and brightness selection

Picture menu:
This menu will permit select the image, whether to play a sound when ready to start showing the image, brightness and delay. The brightness refers to the colour brightness and the delay sets the time between the image rows. A recommended configuration for brightness would be 5% and around 25-30ms in the case of the delay. Note than in the case of brightness even a 100% setting the colour may not be pure due to the power current.

In order to select the picture, move to the line below ‘Current file’ and press the select button, which will show the images found in the microSD card. Note that in this version a maximum of 12 images will be shown. Besides, the images can be even two directories deep, though it has been tested that putting them all in the root directory results in a faster read of available files.


Figure 22: Picture menu

### 7. GIMP Image Formatting

Note: This section was entirely written by Pablo de Miguel Morales, with only a few additional notes from me.

The following Steps cover the preparation of a standard image into a LightWand .pnm compatible image usign the free software program GIMP.

### 7.1. Step 1: Choose an Image

The first step consists in finding a proper Image to be displayed with the LightWand. In general, the two things to be considered are:

- An Aspect Ratio not superior to 1x2. The reason for this is that, as it has a fixed 144LED 1m side, a larger Aspect Ratio will mean having final images taller than 2m. This can be challenging for the user holding the LightWand. In case the image is mean to be horizontal, no limits are considered.
- A not extremely detailed Image. Even do 144 Pixels are quite a good resolution, it cannot be expected for the LightWand to display an extremely accurate image.

For this guide, the image chosen has been “The Kiss” by Gustav Klimt¹
:

1
The Kiss(Gustav Klimt)(1909), Wikipedia, http://en.wikipedia.org/wiki/The_Kiss_%28Klimt%29

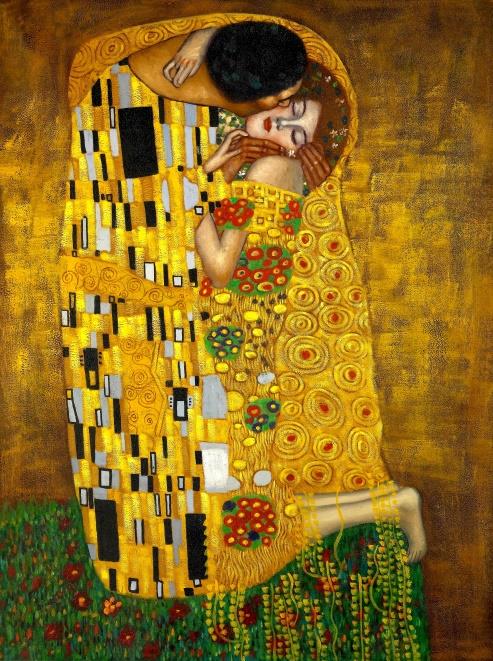
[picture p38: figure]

Figure 23: Gustav Klimt Raw Image

The resolution chosen for this raw image is of 3768x5051. The higher the resolution, the better results will the final image have, as any change (contrast correction, brightness correction) in a LOW quality image will be a lot more noticeable.

Once a proper image has been chosen, the next step can be started.

### 7.2. Step 2: Open the Image with GIMP

The second Step consists in opening the image with GIMP through File/Open.


Figure 24: GIMP File Open

Once the Image has been opened, the next step can be started.

### 7.3. Step 3: Cut the desired section of the Image

The third step consists in cutting the part of the image that is to be displayed. This normally consists of separating the main figure from the rest of the image. Through this process the Canvas is eliminated, improving a lot the final image as no straight lines or edges exists. Without these straight lines, any mistake in the Photographic process is less noticeable.

To cut the desired Image, first duplicate the original layer doing right click in the layer in the Layer Window and selecting Duplicate Layer.

Figure 25: GIMP Duplicate Layer

Once the layer has been duplicated, cut the main figure with the Free-selection tool (Shortcut I). This process can be long and tiring. Once it has been cut, transfer it to a new layer using To new Layer (Shortcut Ctrl+Shift+N).

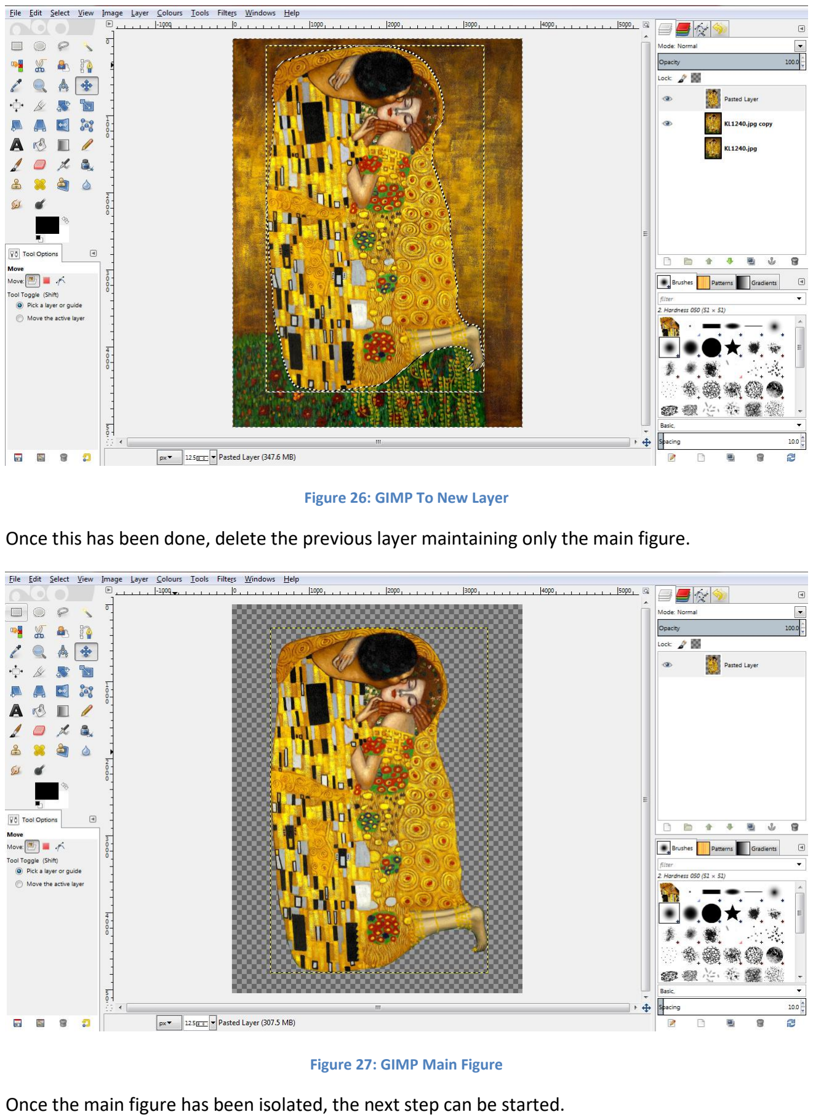
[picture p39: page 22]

Figure 26: GIMP To New Layer

Once this has been done, delete the previous layer maintaining only the main figure.

Figure 27: GIMP Main Figure

Once the main figure has been isolated, the next step can be started.

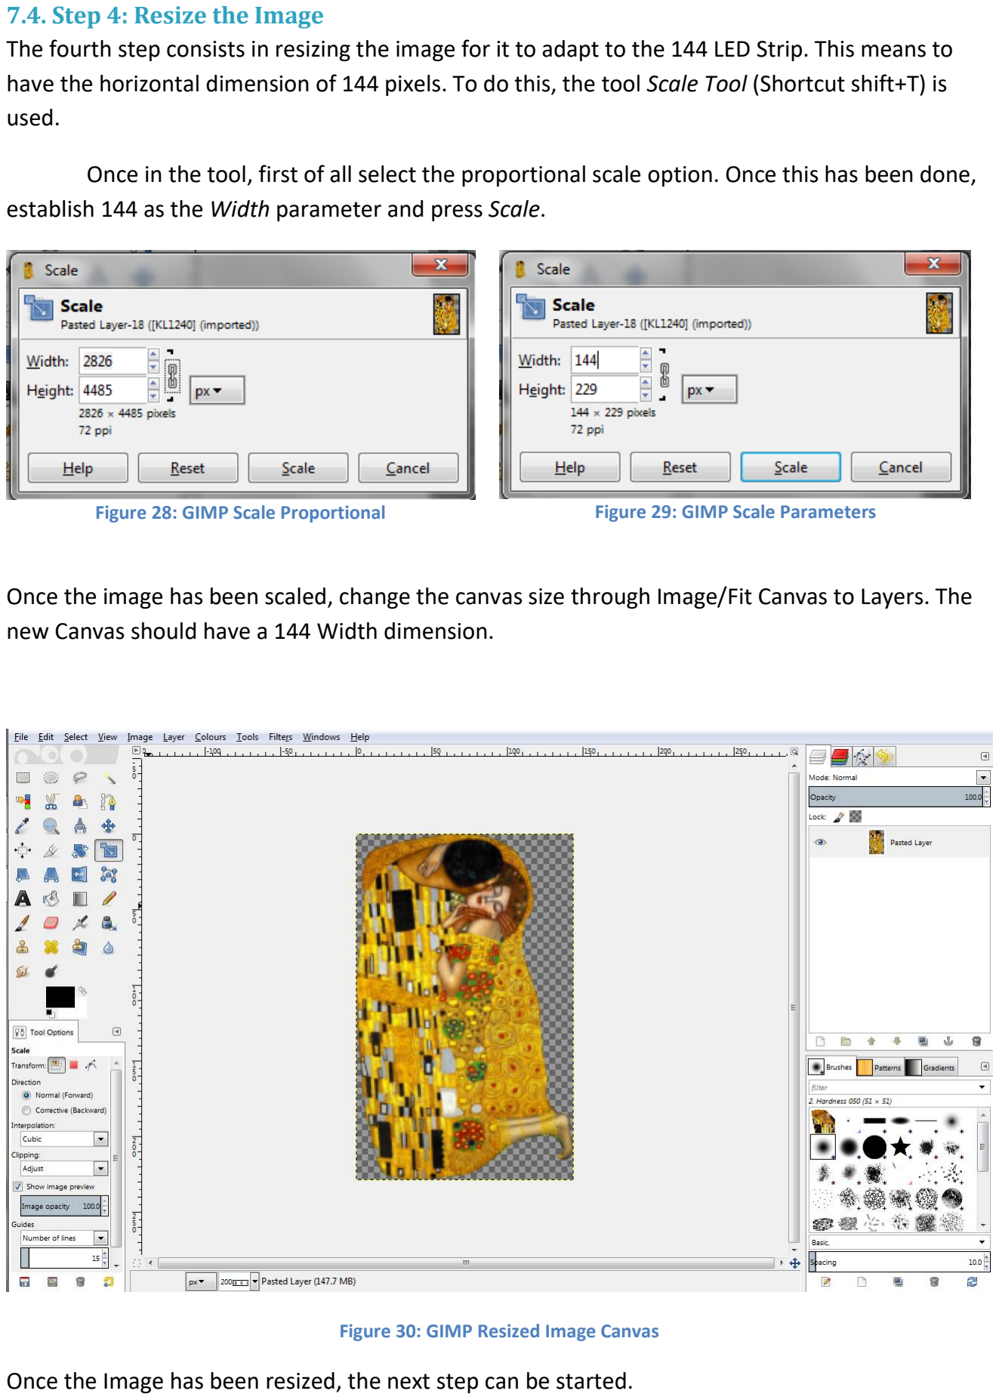
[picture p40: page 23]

### 7.4. Step 4: Resize the Image

The fourth step consists in resizing the image for it to adapt to the 144 LED Strip. This means to have the horizontal dimension of 144 pixels. To do this, the tool Scale Tool (Shortcut shift+T) is used.

Once in the tool, first of all select the proportional scale option. Once this has been done, establish 144 as the Width parameter and press Scale.

Figure 28: GIMP Scale Proportional | Figure 29: GIMP Scale Parameters

Once the image has been scaled, change the canvas size through Image/Fit Canvas to Layers. The new Canvas should have a 144 Width dimension.

Figure 30: GIMP Resized Image Canvas

Once the Image has been resized, the next step can be started.

### 7.5. Step 5: Turn the Image 180º (only if moving the lightwand from the bottom to the

top)
The fifth step consists in turning the image around for it to be displayed from down to up. This step is only important if the image has to be in contact with the ground. Otherwise, this step can be skipped. To turn the image use the Rotate Tool (Shortcut Shift+R) and make a 180º flip.

Figure 31: GIMP Image Rotation

The LightWand reads the images starting from the top pixel row, therefore, that is the first displayed.

### 7.6. Step 6: Add a Black Background

The sixth step consists in adding a black background to the image for it not to be displayed by the LightWand. This can be done in the Layer window by right click New Layer/Foreground Color.

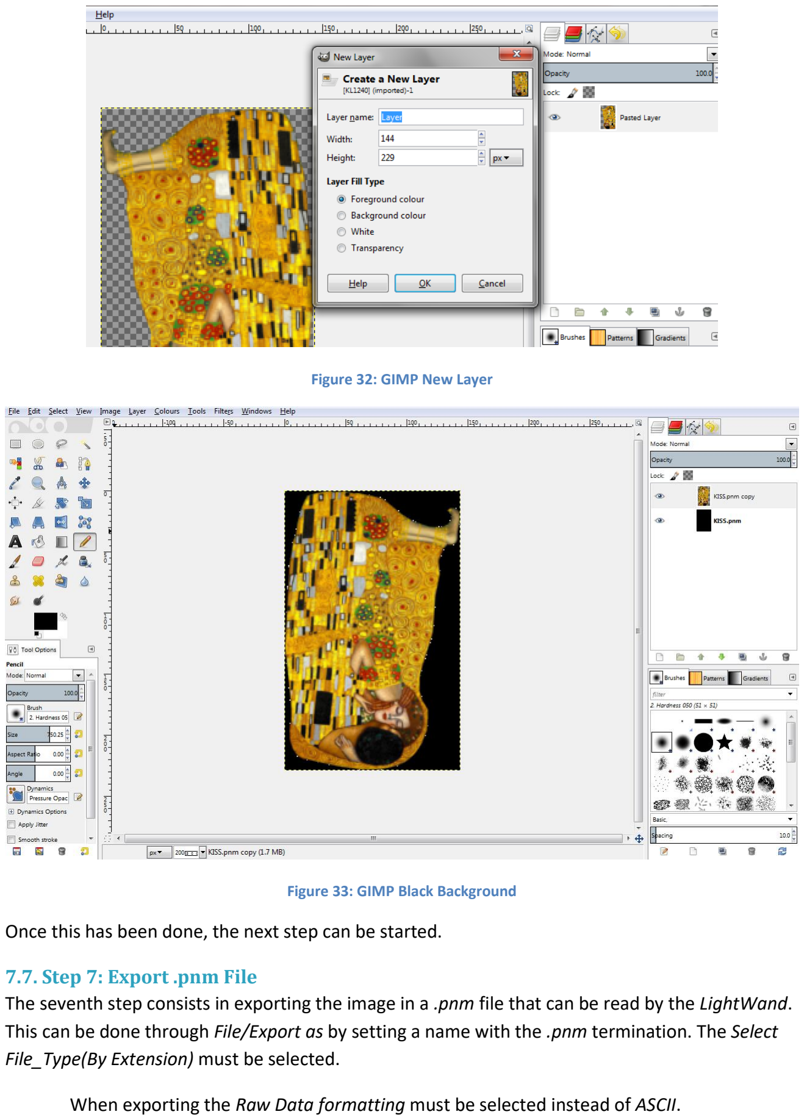
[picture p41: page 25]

Figure 32: GIMP New Layer

Figure 33: GIMP Black Background

Once this has been done, the next step can be started.

### 7.7. Step 7: Export .pnm File

The seventh step consists in exporting the image in a .pnm file that can be read by the LightWand. This can be done through File/Export as by setting a name with the .pnm termination. The Select File_Type(By Extension) must be selected.

When exporting the Raw Data formatting must be selected instead of ASCII.

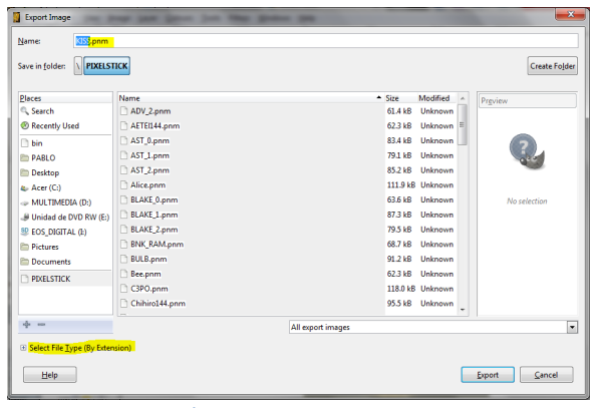
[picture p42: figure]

Figure 34: GIMP Export

Figure 35: GIMP Raw .pnm Mode

Once this step has been done, the GIMP process is finished and the image file can be stored in the SD Card.

### 8. Mobile camera setup

In order to be able to take pictures with a mobile camera, it is required to use the light painting mode (if available) or set up a manual mode. You may find that your camera is not compatible, but most of the recent mobile devices have an improved camera that will let you take photos using light painting techniques. Applications like Camera FV-5 can be useful for this photography technique.

The following example shows how to set a manual mode using the camera of the Aquaris X5, which will be probably similar to other mobile devices:

- With the camera application open, press the circle with the A in order to later choose the manual mode (a circle with the letter M):

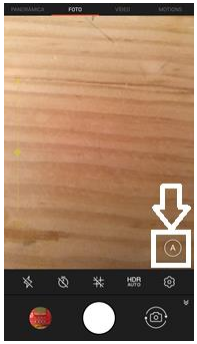
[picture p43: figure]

Figure 36: Press the Auto mode button

Figure 37: Press the Manual option

- Firstly, select autofocus, so the camera will do it by itself:


Figure 38: Autofocus selection

- Secondly, select an automatic white balance, so the camera will do it by itself:

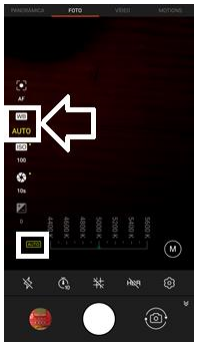
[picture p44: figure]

Figure 39: White balance selection

- Thirdly, select the lowest ISO possible. This way, the images will have much less noise:

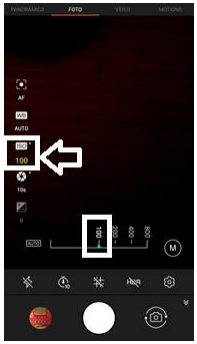
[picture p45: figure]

Figure 40: ISO selection

- -Next, select the shoot time. This time will depend on what is going to be photographed, but usually a 10 second shoot should be fine:

Figure 41: Shoot time

- Finally, select the delay time before taking the shoot, so you can have time to prepare unless someone else can press the button in the proper moment:

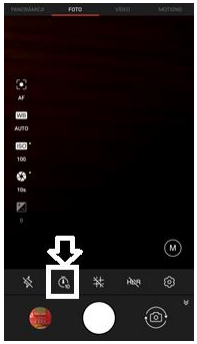
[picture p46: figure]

Figure 42: Start delay time

### 9. Power recommendations

In order to have images with good colour, it is recommended using a Power Bank with 5V and at least 2000 mAh. According to documentation, each LED can consume up to 60mA at full brightness, so 60mA x 144 LEDS = 8,64 A, so in case of willing taking full colour pictures you will need a Power Bank with higher output current.

### 10. Future work

In order to add more options or ease photographing pictures, a Bluetooth and an ADXL345 module were added in the board design, though are yet to be implemented.

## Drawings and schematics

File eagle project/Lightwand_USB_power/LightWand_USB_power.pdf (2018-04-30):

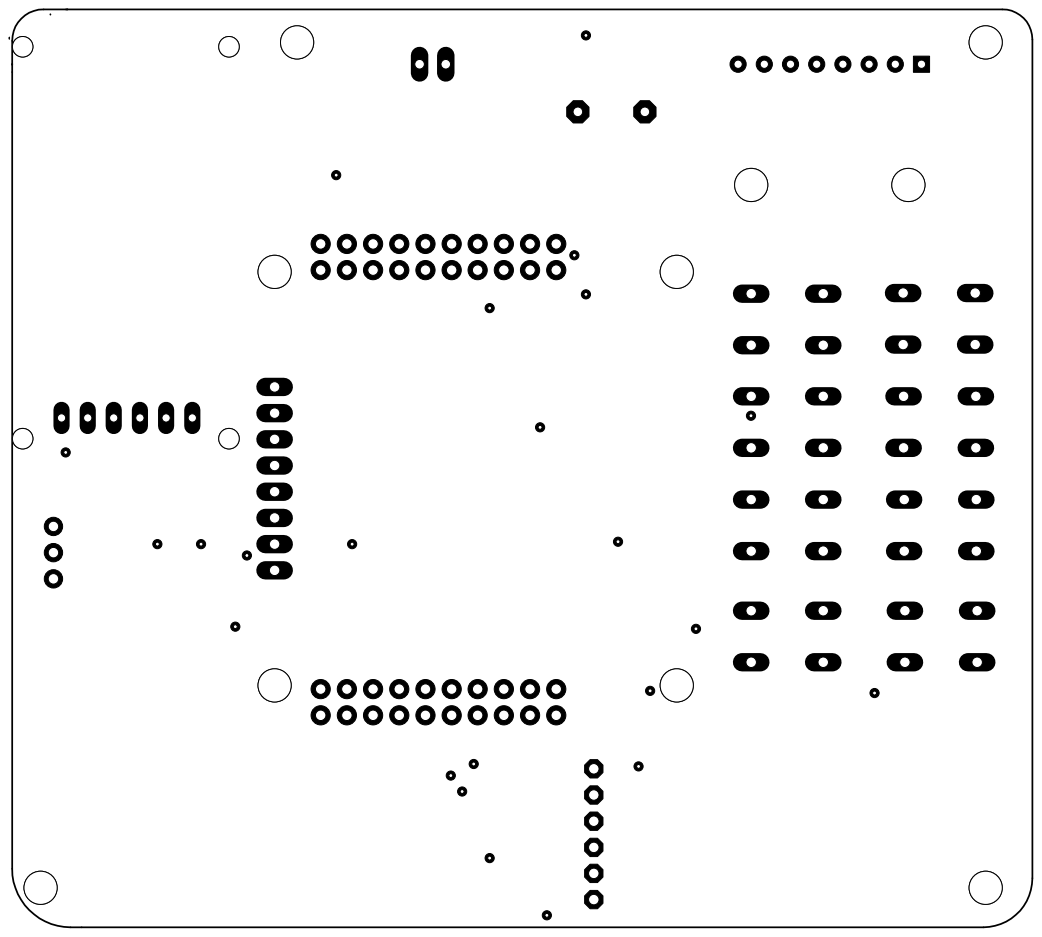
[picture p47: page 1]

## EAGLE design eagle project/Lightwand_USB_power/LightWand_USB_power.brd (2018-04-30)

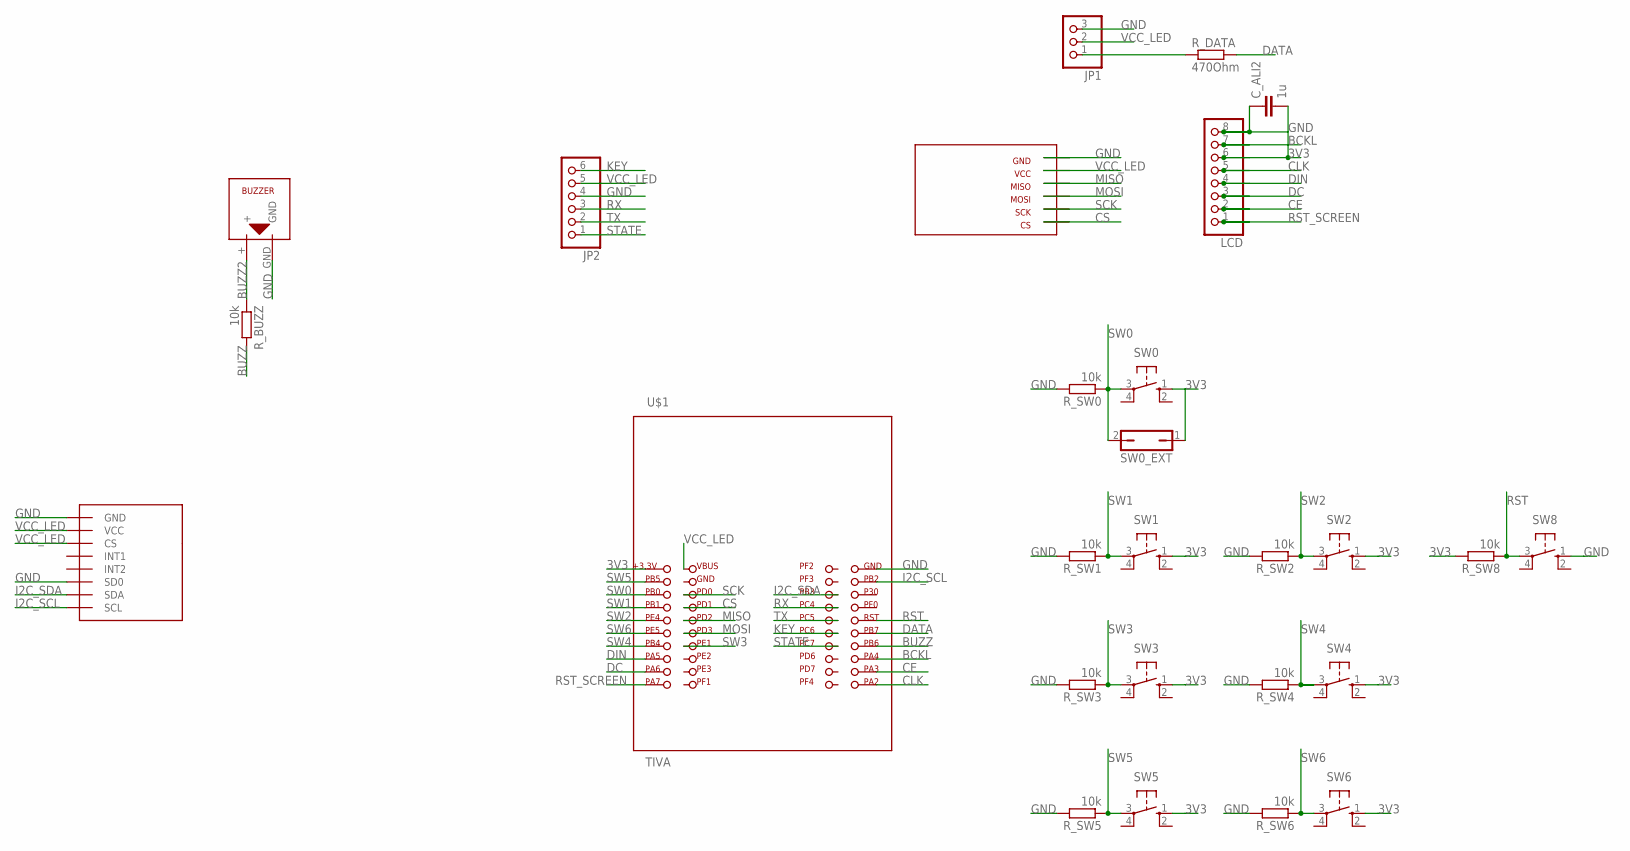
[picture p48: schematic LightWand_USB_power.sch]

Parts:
C_ALI2: 1u; C1206
JP1: PINHD-1X3; 1X03
JP2: PINHD-1X6; 1X06
LCD: PINHD-1X8; 1X08
R_BUZZ: 10k; R1206
R_DATA: 470Ohm; R1206
R_SW0, R_SW1, R_SW2, R_SW3, R_SW4, R_SW5, R_SW6, R_SW8: 10k; R1206
SW0, SW1, SW2, SW3, SW4, SW5, SW6, SW8: 10-XX; B3F-10XX
SW0_EXT: JP1Q; JP1
U$1: TIVA; TIVACSERIES
U$2: ADXL345
U$3: MURATA_BUZZER
U$4: SD_READER_CATALEX

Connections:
3V3: C_ALI2.2, LCD.6, R_SW8.2, SW0.1 (S), SW0_EXT.1, SW1.1 (S), SW2.1 (S), SW3.1 (S), SW4.1 (S), SW5.1 (S), SW6.1 (S), U$1.+3.3V (3.3V)
BCKL: LCD.7, U$1.PA4
BUZZ: R_BUZZ.2, U$1.PB6
BUZZ2: R_BUZZ.1, U$3.+
CE: LCD.2, U$1.PA3
CLK: LCD.5, U$1.PA2
CS: U$1.PD1, U$4.CS
DATA: R_DATA.2, U$1.PB7
DC: LCD.3, U$1.PA6
DIN: LCD.4, U$1.PA5
GND: C_ALI2.1, JP1.3, JP2.4, LCD.8, R_SW0.2, R_SW1.2, R_SW2.2, R_SW3.2, R_SW4.2, R_SW5.2, R_SW6.2, SW8.1 (S), U$1.GND1 (GND2), U$2.P$1 (GND), U$2.P$6 (SD0), U$3.GND, U$4.GND
I2C_SCL: U$1.PB2, U$2.P$7 (SCL)
I2C_SDA: U$1.PB3, U$2.P$8 (SDA)
KEY: JP2.6, U$1.PC6
MISO: U$1.PD2, U$4.MISO
MOSI: U$1.PD3, U$4.MOSI
unnamed: JP1.1, R_DATA.1
RST: R_SW8.1, SW8.3, U$1.RST
RST_SCREEN: LCD.1, U$1.PA7
RX: JP2.3, U$1.PC4
SCK: U$1.PD0, U$4.SCK
STATE: JP2.1, U$1.PC7
SW0: R_SW0.1, SW0.3, SW0_EXT.2, U$1.PB0
SW1: R_SW1.1, SW1.3, U$1.PB1
SW2: R_SW2.1, SW2.3, U$1.PE4
SW3: R_SW3.1, SW3.3, U$1.PE1
SW4: R_SW4.1, SW4.3, U$1.PB4
SW5: R_SW5.1, SW5.3, U$1.PB5
SW6: R_SW6.1, SW6.3, U$1.PE5
TX: JP2.2, U$1.PC5
VCC_LED: JP1.2, JP2.5, U$1.VBUS, U$2.P$2 (VCC), U$2.P$3 (CS), U$4.VCC

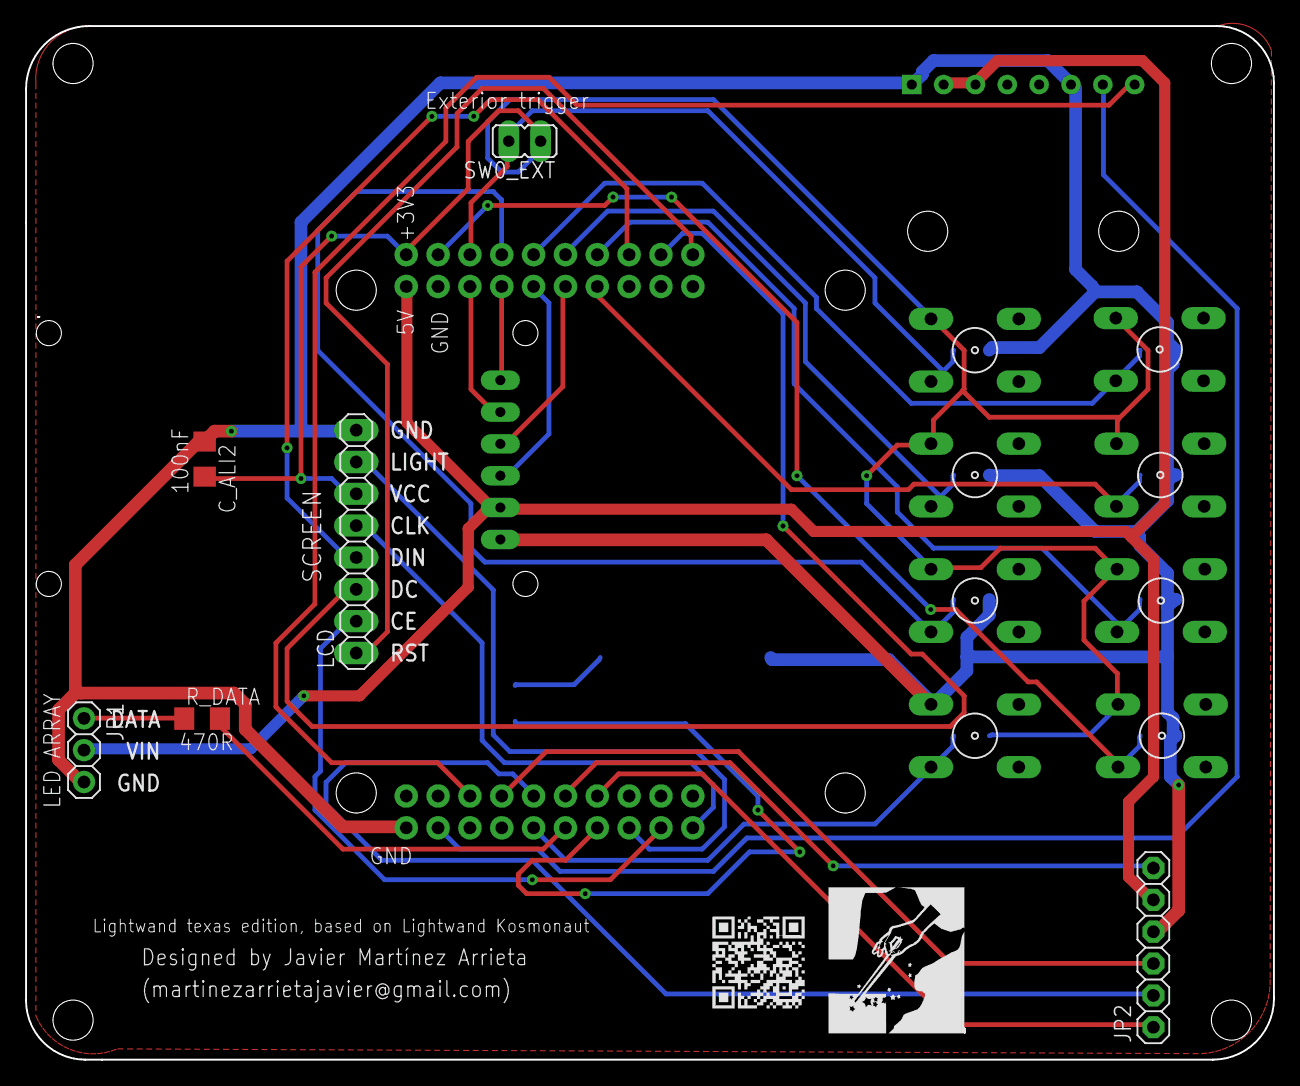
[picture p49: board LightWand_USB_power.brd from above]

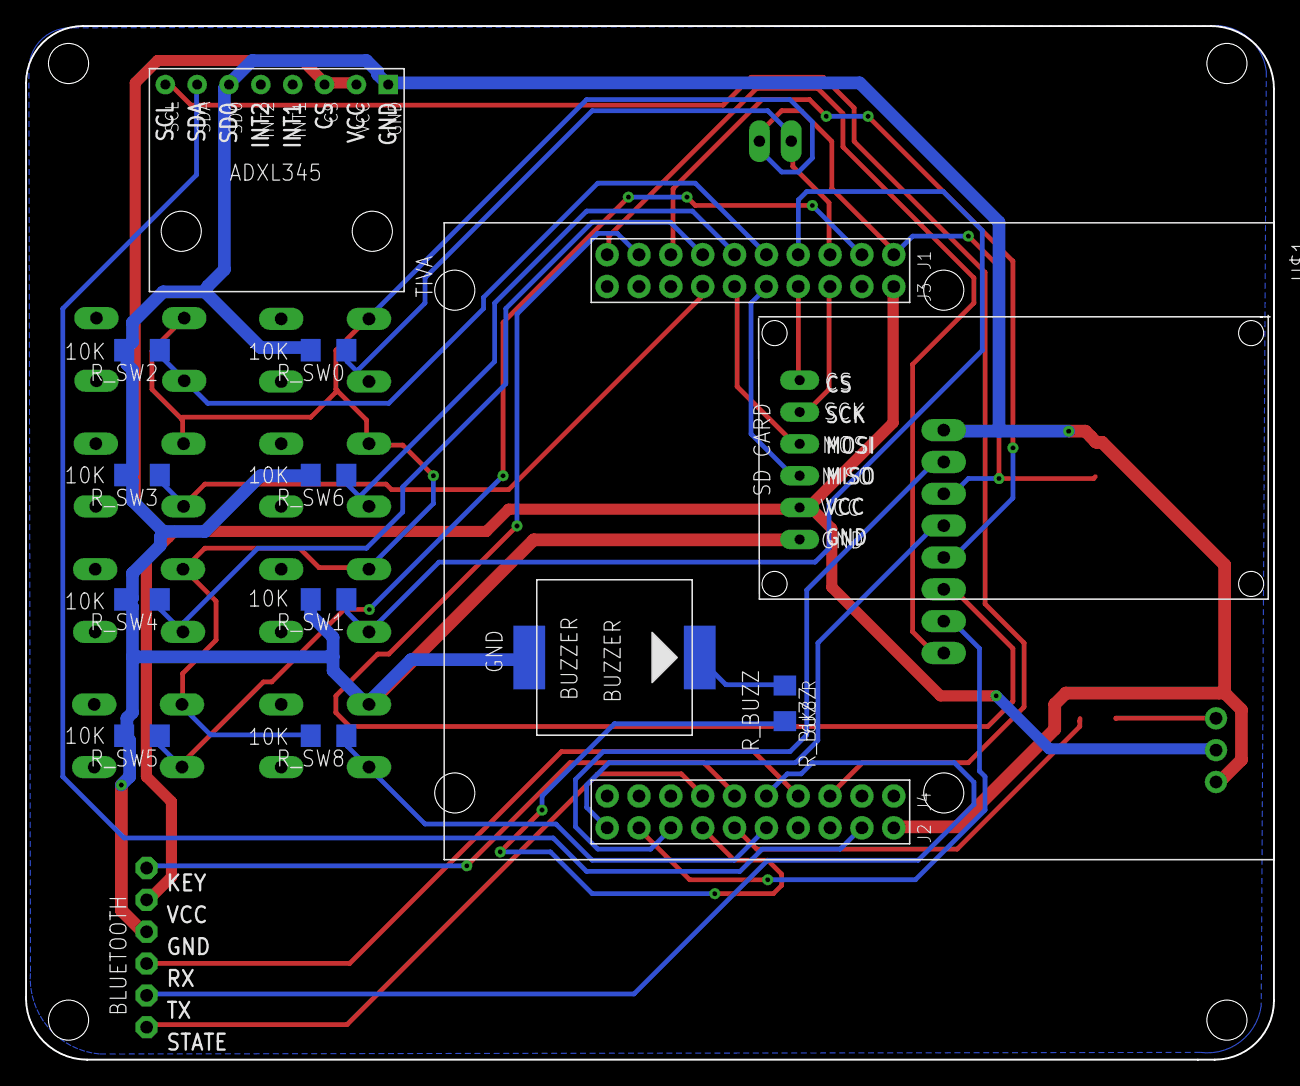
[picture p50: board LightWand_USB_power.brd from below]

Board: 2 copper layers, 99.5 x 82.4 mm, 27 parts (13 on the bottom side), 31 nets.

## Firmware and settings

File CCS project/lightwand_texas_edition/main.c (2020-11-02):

/*
 * main.c
 */

#include "Nokia5110.h"
#include "sdcard.h"
#include "1wire.h"
#include "uart.h"
#include <stdint.h>
#include <string.h>


#define SW1 0

#define MIN_BRIGHT 5
#define MIN_DELAY 5
#define MAX_BRIGHT 100
#define MAX_DELAY 995
#define BL_ON 1
#define BL_OFF 0
#define MAIN_MENU 2
#define FILE_MENU 3
#define BUZZER_ON 4
#define BUZZER_OFF 5
#define INIT_MENU 6
#define PAINT_MENU 7
#define COLOR_MENU 8
#define CURRENTLY_PAINTING 9
#define RED 10
#define GREEN 11
#define BLUE 12
#define RESET_COLORS 13
#define LIGHTS_OFF 14
#define LIGHTS_ON 15


void initialize_buttons(void);
void SysTick_Init(void);
void init_buzzer(uint16_t period, uint16_t high);
void SysTick_Wait50ms(unsigned long delay);
uint8_t map(uint8_t x, uint8_t in_min, uint8_t in_max, uint8_t out_min, uint8_t out_max);
void SysTick_Wait(unsigned long delay);
void set_init_menu(void);
void set_main_picture_menu(void);
void manage_picture_menu(void);
void set_paint_menu(void);
void manage_paint_menu(void);
void set_led_array_to_0(void);

char menu=INIT_MENU;
char backlight=BL_ON;
char buzzer=BUZZER_OFF,subdir=0,max_menu_items=0;
int8_t file_pos=-1;
int bright=5,delay=25,current_position=1;
char go_back=0;
int led_position=0;
uint8_t color=-1, paint=0, painted = 0;
int led_position_red=1, led_position_green=1, led_position_blue=1;
char led_colors[144][3];
int main(void)
{
	SysTick_Init();
	init_buzzer(5000,0);
	init_1wire_pin();
	startSSI0();
	initialize_screen(BACKLIGHT_ON);
	clear_screen();
	/*screen_write("Testing\ncolors...",ALIGN_CENTRE_CENTRE,SSI0);*/
	//test_colors();
	/*clear_screen();*/
	sd_startSSI3();
	initialise_sd(SD_SSI3);
	cs_high(/*SD_SSI3*/);
	change_speed(SD_SSI3);
	cs_low(/*SD_SSI3*/);
	read_first_sector(SD_SSI3);
	read_disk_data(SD_SSI3);
	unsigned long reserved_sectors=get_reserved_sectors();
	if(reserved_sectors==1)
	{
		//Message to be shown if not FAT32 (single format)
		screen_write("Invalid\nSD card\nformat",ALIGN_CENTRE_CENTRE);
	}
	else
	{
	    //Set all leds in array to 0
	    set_led_array_to_0();
		long next_cluster=get_root_dir_first_cluster();
		screen_write("Initialising...",ALIGN_CENTRE_CENTRE);
		do
		{
			next_cluster=get_files_and_dirs(next_cluster,LONG_NAME,GET_SUBDIRS,SD_SSI3);
		}while(next_cluster!=0x0FFFFFFF && next_cluster!=0xFFFFFFFF);
		filter_by_extension("pnm",1);
		clear_screen();
		set_init_menu();
		initialize_buttons();
		current_position=2;
		show_menu(2);
		while(1)
		{
		    if(paint == 1 && painted == 0)
		    {
		        char c,c2,k;
		        for(c=0;c<144;c++)
		        {
		            for(c2=0;c2<3;c2++)
		            {
		                for(k=0;k<8;k++)
		                {
		                    if(led_colors[c][c2] & (0x80 >> k))
		                    {
		                        send_bit(1);
		                    }
		                    else
		                    {
		                        send_bit(0);
		                    }
		                }
		            }
		        }
		        painted = 1;
		    }
		    /*if(GPIO_PORTE_DATA_R&0x10)
		    {
		        increase_value();
		    }*/
			/*char keep_going=0;
			while(keep_going==0)
			{
				char portB_data=GPIO_PORTB_DATA_R&0x33;
				char portE_data=GPIO_PORTE_DATA_R&0x32;
				if(portB_data > 0x00)
				{
					switch(portB_data)
					{
						case 0x01: //PB0 (Change backlight status)
						{

						break;
						}
						case 0x02: //PB1 (Select element at current position)
						{
							if(current_position==2)
							{
								menu = PAINT_MENU;
							}
							else
							{
								menu = MAIN_MENU;
							}
							keep_going=1;
							break;
						}

					}
				}
				if(portE_data > 0x00)
				{
					switch(portE_data)
					{
						case 0x02: // PE1 (down)
						{
							if(current_position==2)
							{
								current_position=3;
							}
							break;
						}
						case 0x20: // PE5 (up)
						{
							if(current_position==3)
							{
								current_position=2;
							}
							break;
						}
					}
					show_menu(current_position);
				}
			}
			clear_screen();
			delete_menu();
			if(menu==MAIN_MENU)
			{
				initialise_uart();
				//ask_for_bluetooth();
				//send_files_info();
				clear_screen();
				set_main_picture_menu();
				show_menu(1);
				current_position=1;
				manage_picture_menu();
			}
			else
			{
				set_paint_menu();
				show_menu(1);
				current_position=1;
				manage_paint_menu();
			}*/
		}
		/*initialize_I2C();
		initialize_accelerometer();
		read_accelerometer_data();*/
	}
	return 0;
}

void set_led_array_to_0()
{
    int i=0;
    for(i=0;i<144;i++)
    {
        led_colors[i][0] = 0x00;
        led_colors[i][1] = 0x00;
        led_colors[i][2] = 0x00;
    }
}

void send_files_info()
{
	int i=0,j=0;
	UART_OutChar('<');
	for(i=0;i<12;i++)
	{
		unsigned char name[25];
		get_name(i,name);
		if(name[0]!=0x00)
		{
			for(j=0;j<25;j++)
			{
				UART_OutChar(name[j]);
			}
			UART_OutChar('\n');
			//UART_OutChar('');
		}
	}
	UART_OutChar('<');
}

void ask_for_bluetooth()
{
	screen_write("Set the\nsettings\nthrough\nBluetooh?",ALIGN_CENTRE_CENTRE);
	bright=(int) UART_InChar();
	delay=(int) UART_InChar();
	UART_OutChar('1');
}

void set_init_menu()
{
	add_menu_element("Lightwand");
	add_menu_element("Select option");
	add_menu_element("1. Paint");
	add_menu_element("2. Picture");
	max_menu_items=4;
}

void set_main_picture_menu()
{
	add_menu_element("<-Main menu");
	/*char cad[14]="Bright: ";
	convert_value_to_string(cad, bright);
	strcat(cad," %");
	add_menu_element(cad);
	strcpy(cad,"Delay: ");
	convert_value_to_string(cad, delay);
	strcat(cad," ms");
	add_menu_element(cad);*/
	add_menu_element("Bright: 5 %");
	add_menu_element("Delay: 25 ms");
	add_menu_element("Current file:");
	add_menu_element("None");
	add_menu_element("Buzzer: off");
	max_menu_items=6;
}

void set_paint_menu()
{
	add_menu_element("Select color:");
	add_menu_element("Red");
	add_menu_element("Green");
	add_menu_element("Blue");
	add_menu_element("Random");
	add_menu_element("Monochrome");
	add_menu_element("Reset");
	max_menu_items=7;
}

void set_color_menu()
{
	add_menu_element("Select LED");
    char str[15];
	switch(color)
	{
	    case RED:
	    {
	        sprintf(str, "LED (R): %d", led_position_red);
	        break;
	    }
	    case GREEN:
	    {
	        sprintf(str, "LED (G): %d", led_position_green);
	        break;
	    }
	    case BLUE:
	    {
	        sprintf(str, "LED (B): %d", led_position_blue);
	        break;
	    }
	}
	add_menu_element(str);
	add_menu_element("Bright: 5 %");
	add_menu_element("<- Back");
	max_menu_items=4;
}

void set_color_brightness_menu()
{
	add_menu_element("Select brightness");
	add_menu_element("Bright: 5 %");
	add_menu_element("<- Back");
	max_menu_items=3;
}

void initialize_buttons(void)
{
    volatile unsigned long delay;
    SYSCTL_RCGC2_R |= 0x00000012;           //  activate clock for Ports B and E
    delay = SYSCTL_RCGC2_R;                 //  allow time for clock to stabilize
    GPIO_PORTB_DIR_R &= ~0x33;             // make PB0,1,4 and 5 in
    GPIO_PORTB_AFSEL_R &= ~0x33;           // disable alt funct on PA2,3,5
    GPIO_PORTB_DEN_R |= 0x33;             // enable digital I/O on PB0,1,4 and 5

    GPIO_PORTB_PCTL_R &= ~0x00FF00FF;    //Configure PB0, 1, 4 and 5 as GPIO
    GPIO_PORTB_AMSEL_R &= ~0x33;           // disable alt funct on PB0,1,4 and 5
    GPIO_PORTB_IS_R &= ~0x33;            //PB0,1,4 and 5 are edge sensitive
    GPIO_PORTB_IBE_R &= ~0x33;            //Disable both edges for PB0,1,4 and 5
    //GPIO_PORTB_IEV_R &= ~0x33;            //Detect falling edge in PB0,1,4 and 5
    GPIO_PORTB_IEV_R |= 0x33;            //Detect rising edge in PB0,1,4 and 5
    GPIO_PORTB_ICR_R = 0x33;              // ack, clear interrupt flags for PB0,1,4 and 5
    GPIO_PORTB_IM_R |= 0x33;              // arm interrupt on PB0,1,4 and 5
    NVIC_PRI0_R = (NVIC_PRI0_R&0xFFFF1FFF)|0x0000E000;         //Set priority bits for port B
    NVIC_EN0_R |= 0x00000002;      // (h) enable interrupt 1 in NVIC (seen in IRQ). Interrupt one is bit 1


    GPIO_PORTE_DIR_R &= ~0x32;             // make PE1,4 and 5 in
    GPIO_PORTE_AFSEL_R &= ~0x32;           // disable alt funct on PE1,4 and 5
    GPIO_PORTE_DEN_R |= 0x32;             // enable digital I/O on PE1,4 and 5


    GPIO_PORTE_PCTL_R &= ~0x00FF00F0;    //Configure PE1,4 and 5 as GPIO
    GPIO_PORTE_AMSEL_R &= ~0x32;           // disable alt funct on PE1, 4 and 5
    GPIO_PORTE_IS_R &= ~0x32;            //PE1, 4 and 5 are edge sensitive
    GPIO_PORTE_IBE_R &= ~0x32;            //Disable both edges for PE1, 4 and 5
    //GPIO_PORTE_IEV_R &= ~0x32;            //Detect falling edge in PE1, 4 and 5
    GPIO_PORTE_IEV_R |= 0x32;            //Detect rising edge in PE1, 4 and 5
    GPIO_PORTE_ICR_R = 0x32;              // ack, clear interrupt flags for PE1, 4 and 5
    GPIO_PORTE_IM_R |= 0x32;              // arm interrupt on PE1, PE4 and PE5
    NVIC_PRI1_R = (NVIC_PRI1_R&0xFFFFFF1F)|0x000000E0;         //Set priority bits for port E
    NVIC_EN0_R |= 0x00000010;      // (h) enable interrupt 1 in NVIC (seen in IRQ). Interrupt one is bit 4

    IntMasterEnable();          //Enable global interrupts
}

void GPIOPortB_Handler(void)
{
    int led_position=0;
    char c,c2,go_back=0,just_came=0;
    //Check which pin caused the interrupt
    //Backlight pin (PB0)
    if(GPIO_PORTB_RIS_R&0x01)
    {
        GPIO_PORTB_ICR_R |= 0x01; // ack, clear interrupt flag0
        if(backlight==BL_ON)
        {
            disable_backlight(/*SSI0*/);
            backlight=BL_OFF;
        }
        else
        {
            enable_backlight(/*SSI0*/);
            backlight=BL_ON;
        }
    }
    else
    {
        //Minus/decrease pin (PB4)
        if(GPIO_PORTB_RIS_R&0x10)
        {
            GPIO_PORTB_ICR_R |= 0x10; // ack, clear interrupt flag4
            decrease_value();
        }
        else
        {
            //Select pin (PB1)
            if(GPIO_PORTB_RIS_R&0x02)
            {
                GPIO_PORTB_ICR_R |= 0x02; // ack, clear interrupt flag1
                switch(menu)
                {
                    case MAIN_MENU:
                    {
                        switch(current_position)
                        {
                            case 0:
                            {
                                delete_menu();
                                clear_screen();
                                set_init_menu();
                                current_position=2;
                                show_menu(2);
                                menu=INIT_MENU;
                                break;
                            }
                            case 4:
                            {
                                subdir++;
                                backup_main_menu();
                                //Change to file_menu
                                delete_menu();
                                clear_screen();
                                char i;
                                max_menu_items=0;
                                for(i=0;i<12;i++)
                                {
                                    unsigned char name[25];
                                    get_name(i,name);
                                    if(name[0]!=0x00)
                                    {
                                        add_menu_element(name);
                                        max_menu_items++;
                                    }
                                }
                                menu=FILE_MENU;
                                current_position=0;
                                show_menu(0);
                                break;
                            }
                        }
                        break;
                    }
                    case FILE_MENU:
                    {
                        //Change to main menu, showing the name of the selected file
                        //Is it a file?
                        char type=is_file_or_dir(current_position);
                        if(type == 2)
                        {
                            copy_menu();
                            delete_menu();
                            file_pos=current_position;
                            clear_screen();
                            subdir=0;
                            restore_main_menu();
                            unsigned char name[25];
                            get_name(file_pos,name);
                            modify_menu_element(4,name);
                            menu=MAIN_MENU;
                            current_position=4;
                            reset_min_max();
                            show_menu(4);
                        }
                        else
                        {
                            copy_menu();
                            delete_menu();
                            subdir++;
                            long next_cluster=get_first_cluster(current_position);
                            do
                            {
                                next_cluster=list_dirs_and_files(next_cluster,SHORT_NAME,NO_SUBDIRS,SD_SSI3);
                            }while(next_cluster!=0x0FFFFFFF && next_cluster!=0xFFFFFFFF);
                            char i;
                            clear_screen();
                            max_menu_items=0;
                            for(i=0;i<12;i++)
                            {
                                unsigned char name[25];
                                get_name(i,name);
                                if(name[0]!=0x00)
                                {
                                    add_menu_element(name);
                                    max_menu_items++;
                                }
                            }
                            current_position=0;
                            clear_screen();
                            show_menu(0);
                        }
                        break;
                    }
                    case INIT_MENU:
                    {
                        switch(current_position)
                        {
                            case 2:
                            {
                                menu=PAINT_MENU;
                                copy_menu();
                                clear_screen();
                                delete_menu();
                                set_paint_menu();
                                current_position=1;
                                show_menu(1);
                                break;
                            }
                            case 3:
                            {
                                menu=MAIN_MENU;
                                copy_menu();
                                delete_menu();
                                clear_screen();
                                set_main_picture_menu();
                                current_position=1;
                                show_menu(1);
                                break;
                            }
                        }
                        break;
                    }
                    case PAINT_MENU:
                    {
                        switch(current_position)
                        {
                            case 1:
                            {
                                color=RED;
                                clear_screen();
                                delete_menu();
                                set_color_menu();
                                show_menu(1);
                                menu=COLOR_MENU;
                                led_position=1;
                                break;
                            }
                            case 2:
                            {
                                color=GREEN;
                                clear_screen();
                                delete_menu();
                                set_color_menu();
                                show_menu(1);
                                current_position=1;
                                menu=COLOR_MENU;
                                led_position=1;
                                break;
                            }
                            case 3:
                            {
                                color=BLUE;
                                clear_screen();
                                delete_menu();
                                set_color_menu();
                                show_menu(1);
                                current_position=1;
                                menu=COLOR_MENU;
                                led_position=1;
                                break;
                            }
                            case 4:
                            {//random
                                clear_ledarray();
                                clear_screen();
                                screen_write("Generating...",ALIGN_CENTRE_CENTRE);
                                srand(time(NULL));
                                for(c=0;c<144;c++)
                                {
                                    for(c2=0;c2<3;c2++)
                                    {
                                        led_colors[c][c2]=rand()%255;
                                    }
                                }
                                clear_screen();
                                set_paint_menu();
                                show_menu(1);
                                current_position=1;
                                //menu=COLOR_MENU;
                                break;
                            }
                            case 5:
                            {//monochrome
                                clear_ledarray();
                                for(c=0;c<144;c++)
                                {
                                    for(c2=0;c2<3;c2++)
                                    {
                                        if(c%2==0)
                                        {
                                            led_colors[c][c2]=0;
                                        }
                                        else
                                        {
                                            led_colors[c][c2]=25;
                                        }
                                    }
                                }
                                break;
                            }
                            case 6:
                            {
                                clear_ledarray();
                                for(c=0;c<144;c++)
                                {
                                    for(c2=0;c2<3;c2++)
                                    {
                                        led_colors[c][c2]=0;
                                    }
                                }
                                break;
                            }
                        }
                        break;
                    }
                    case COLOR_MENU:
                    {
                        if(current_position==3)
                        {
                            delete_menu();
                            menu=PAINT_MENU;
                            clear_screen();
                            set_paint_menu();
                            show_menu(1);
                            current_position=1;
                        }
                        else
                        {
                            if(current_position!=2)
                            {
                                int BrightLimit = map(get_brightness(),0,100,0,255);
                                switch(color)
                                {
                                    case RED:
                                    {
                                        led_colors[led_position_red-1][0]=0;
                                        led_colors[led_position_red-1][1]=map(255,0,255,0,BrightLimit);
                                        led_colors[led_position_red-1][2]=0;
                                        break;
                                    }
                                    case GREEN:
                                    {
                                        led_colors[led_position_green-1][0]=map(255,0,255,0,BrightLimit);
                                        led_colors[led_position_green-1][1]=0;
                                        led_colors[led_position_green-1][2]=0;
                                        break;
                                    }
                                    case BLUE:
                                    {
                                        led_colors[led_position_blue-1][0]=0;
                                        led_colors[led_position_blue-1][1]=0;
                                        led_colors[led_position_blue-1][2]=map(255,0,255,0,BrightLimit);
                                        break;
                                    }
                                }
                            }
                        }
                        break;
                    }
                }
            }
            else
            {
                //Start pin (PB5)
                if(GPIO_PORTB_RIS_R&0x20)
                {
                    GPIO_PORTB_ICR_R |= 0x20; // ack, clear interrupt flag5
                    switch(menu)
                    {
                        case MAIN_MENU:
                        {
                            if(file_pos!=-1)
                            {
                                if(buzzer == BUZZER_ON)
                                {
                                    play_sound(1000);
                                    SysTick_Wait50ms(40);
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

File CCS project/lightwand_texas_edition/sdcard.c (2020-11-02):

/*
 * sdcard.c
 *
 *  Created on: 15/09/2016
 *  Author: Javier Martínez Arrieta
 *  Version: 1.0
 *  This is part of the sdcard library, with functions that will allow you to read and (in the future) write in an SD card formatted using FAT32 (single partition).
 */

 /*  Copyright (C) 2016 Javier Martínez Arrieta
 *
 *  This project is licensed under Creative Commons Attribution-Non Commercial-Share Alike 4.0 International (CC BY-NC-SA 4.0). According to this license you are free to:
 *  Share & copy and redistribute the material in any medium or format.
 *  Adapt & remix, transform, and build upon the material.
 *  The licensor cannot revoke these freedoms as long as you follow the license terms.
 *	Complete information about this license can be found at: https://creativecommons.org/licenses/by-nc-sa/4.0/legalcode
 *
 */


/* Part of this example (partially modified functions rcvr_datablock, rcvr_spi_m, disk_timerproc, Timer5A_Handler, Timer5_Init, is_ready, send_command and part of initialize_sd) accompanies the books
   Embedded Systems: Real-Time Operating Systems for ARM Cortex-M Microcontrollers, Volume 3,
   ISBN: 978-1466468863, Jonathan Valvano, copyright (c) 2013

   Volume 3, Program 6.3, section 6.6   "Embedded Systems: Real Time Interfacing to Arm Cortex M Microcontrollers",
   ISBN: 978-1463590154, Jonathan Valvano, copyright (c) 2013

 Copyright 2013 by Jonathan W. Valvano, valvano@mail.utexas.edu
    You may use, edit, run or distribute this file (concretely the functions mentioned)
    as long as the above copyright notice remains
 THIS SOFTWARE IS PROVIDED "AS IS".  NO WARRANTIES, WHETHER EXPRESS, IMPLIED
 OR STATUTORY, INCLUDING, BUT NOT LIMITED TO, IMPLIED WARRANTIES OF
 MERCHANTABILITY AND FITNESS FOR A PARTICULAR PURPOSE APPLY TO THIS SOFTWARE.
 VALVANO SHALL NOT, IN ANY CIRCUMSTANCES, BE LIABLE FOR SPECIAL, INCIDENTAL,
 OR CONSEQUENTIAL DAMAGES, FOR ANY REASON WHATSOEVER.
 For more information about my classes, my research, and my books, see
 http://users.ece.utexas.edu/~valvano/
 */

#include "sdcard.h"
#include "inc/tm4c123gh6pm.h"
#include "1wire.h"
#include "Nokia5110.h"
#include <stdio.h>


unsigned char Timer1,Timer2;
unsigned long lba_begin_address,number_of_sectors,lba_addr,cluster_start,file_size,cluster_begin_lba,fat_begin_lba,sectors_per_fat=0,root_dir_first_cluster;
unsigned long previous_cluster=0,cluster_dir=0,reserved_sectors=0;
unsigned char sectors_per_cluster=0;
char fd_count=0,current_count=0;
char finish=0,first_file=1;
int row=0,column=0,number=0,rows=0,columns=0,total=0,current=0,BrightLimit,l=0,num=0,num2=0;
//int l=0;
uint8_t pixel_content[NUM_LEDS*3];

typedef struct
{
	char hour;
	char minute;
	unsigned int year;
	char month;
	char day;
	long size;
	long first_cluster;
}tfile_info;

typedef struct
{
	tfile_info info;
	unsigned char file_dir_name[255];
}tfile_name;

typedef struct
{
	tfile_name name;
	enum type_of_file
	{
		IS_NONE,
		IS_DIR,
		IS_FILE
	}type;
}tfile_dir;

tfile_dir file_dir[40];

/**
 * Writes to the SD card. Yet to be tested
 */
void sd_write(char message)
{
	unsigned short volatile rcvdata;
	while((SSI3_SR_R&SSI_SR_TNF)==0){};
	SSI3_DR_R = message;
	while((SSI3_SR_R&SSI_SR_RNE)==0){};
	rcvdata = SSI3_DR_R;
}

/*
 * Reads from the SD card
 */
unsigned char sd_read()
{
	while((SSI3_SR_R&SSI_SR_TNF)==0){};    // wait until room in FIFO
	SSI3_DR_R = 0xFF;                      // data out, garbage
	while((SSI3_SR_R&SSI_SR_RNE)==0){};    // wait until response
	return (unsigned char) SSI3_DR_R;      // read received data
}

/*
 * Wait until sd card is ready
 */
unsigned char is_ready(enum SSI SSI_number){
  unsigned char response;
  Timer2 = 50;    /* Wait for ready in timeout of 500ms */
  do
  {
    response = sd_read();
  }while ((response != 0xFF) && Timer2);
  return response;
}


/*
 * Sends the command, preparing the packet to be sent
 */
unsigned char send_command(unsigned char command, unsigned long argument, enum SSI SSI_number)
{
	/* Argument */
	unsigned char crc, response,n;
	if (is_ready(SSI_number) != 0xFF) return 0xFF;

    /* Send command packet */
	sd_write(command);                        /* Command */
	sd_write((unsigned char)(argument >> 24));        /* Argument[31..24] */
	sd_write((unsigned char)(argument >> 16));        /* Argument[23..16] */
	sd_write((unsigned char)(argument >> 8));            /* Argument[15..8] */
	sd_write((unsigned char)argument);                /* Argument[7..0] */
	crc = 0;
	if (command == CMD0)
	{
		crc = 0x95;            /* CRC for CMD0(0) */
	}
	if (command == CMD8)
	{
		crc = 0x87;            /* CRC for CMD8(0x1AA) */
	}
	sd_write(crc);

    /* Receive command response */
	if (command == CMD12) sd_write(0xFF);        /* Skip a stuff byte when stop reading */
	n = 10;                                /* Wait for a valid response in timeout of 10 attempts */
	do
	{
		response = sd_read();
	}while ((response & 0x80) && --n);
	return response;
}

/*
 * Initializes the SD card
 */
void initialise_sd(enum SSI SSI_number)
{
	unsigned char i;
	unsigned char ocr[4];
	unsigned char sd_type;
	//Sends a 1 through CS and MOSI lines for at least 74 clock cycles
	cs_high();
	dummy_clock();
	cs_low();
	i=0;
	/*Checks if SD card is in IDLE mode. If so, response will be 1*/
	if(send_command(CMD0, 0,SSI_number) == 1)
	{
		Timer1 = 100; /* Initialization timeout of 1000 msec */
		if(send_command(CMD8, 0x1AA,SSI_number) == 1)
		{
			/* SDC Ver2+ */
			for(i=0;i<4;i++)
			{
				ocr[i]=sd_read();
			}
			if(ocr[2]==0x01&&ocr[3]==0xAA)
			{
				//sends ACMD41, which is a command sequence of CMD55 and CMD41
				do
				{
					if(send_command(CMD55, 0, SSI_number) <= 1 && send_command(CMD41, 1UL << 30,SSI_number) == 0)
					{
						break; //R1 response is 0x00
					}
				}while(Timer1);
				if(Timer1 && send_command(CMD58, 0,SSI_number) == 0)
				{
					for(i=0;i<4;i++)
					{
						ocr[i]=sd_read();
						sd_type = (ocr[0] & 0x40) ? 6 : 2;
					}
				}
			}
		}
		else
		{
			/*It is not SD version 2 or upper*/
			sd_type=(send_command(CMD55, 0,SSI_number)<=1 &&send_command(CMD41, 0,SSI_number) <= 1) ? 2 : 1;    /*Check if SD or MMC*/
			do
			{
				if(sd_type==2)
				{
					if(send_command(CMD55, 0,SSI_number)<=1&&send_command(CMD41, 0,SSI_number)==0) /*ACMD41*/
			        {
						break;
			        }
				}
				else
				{
					if (send_command(CMD1, 0,SSI_number) == 0) /*CMD1*/
					{
						break;
					}
			    }
			}while(Timer1);
			if(!Timer1 || send_command(CMD16, 512,SSI_number) != 0)    /*Select R/W block length if timeput not reached*/
			{
				sd_type=0;
			}
		}
	}
}
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

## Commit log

2018-04-30 Lightwand Texas Edition v1.0
    [LightWand_USB_power.GBL, LightWand_USB_power.GBO, LightWand_USB_power.GBP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]
2018-05-01 Added mobile camera setup
2018-05-01 Solved problem with buzzer sound
    [main.c, sdcard.c]
2018-05-27 Guides have been updated with box mount
2018-11-25 Added Bill of Materials
    [BOM (Bill Of Materials).xlsx]
2020-07-25 Update to version 2.0. In this version the code was changed to interrupts
    [1wire.obj, Nokia5110.obj, main.obj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]
